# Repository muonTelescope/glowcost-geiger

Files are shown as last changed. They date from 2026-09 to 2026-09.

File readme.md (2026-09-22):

# gLowCost-geiger

A 3.3 V Geiger module for an SBM-20. An ATtiny1616 PWM-drives a boost into a 4-stage Cockcroft–Walton ladder, counts pulses, and regulates the tube voltage from PA6. Power and I²C come in on STEMMA QT. TTL is a test point. Enable is firmware.

> Prototype. The board matches this schematic's parts. New nets are not fully routed, and the high-voltage design is not bench-qualified.

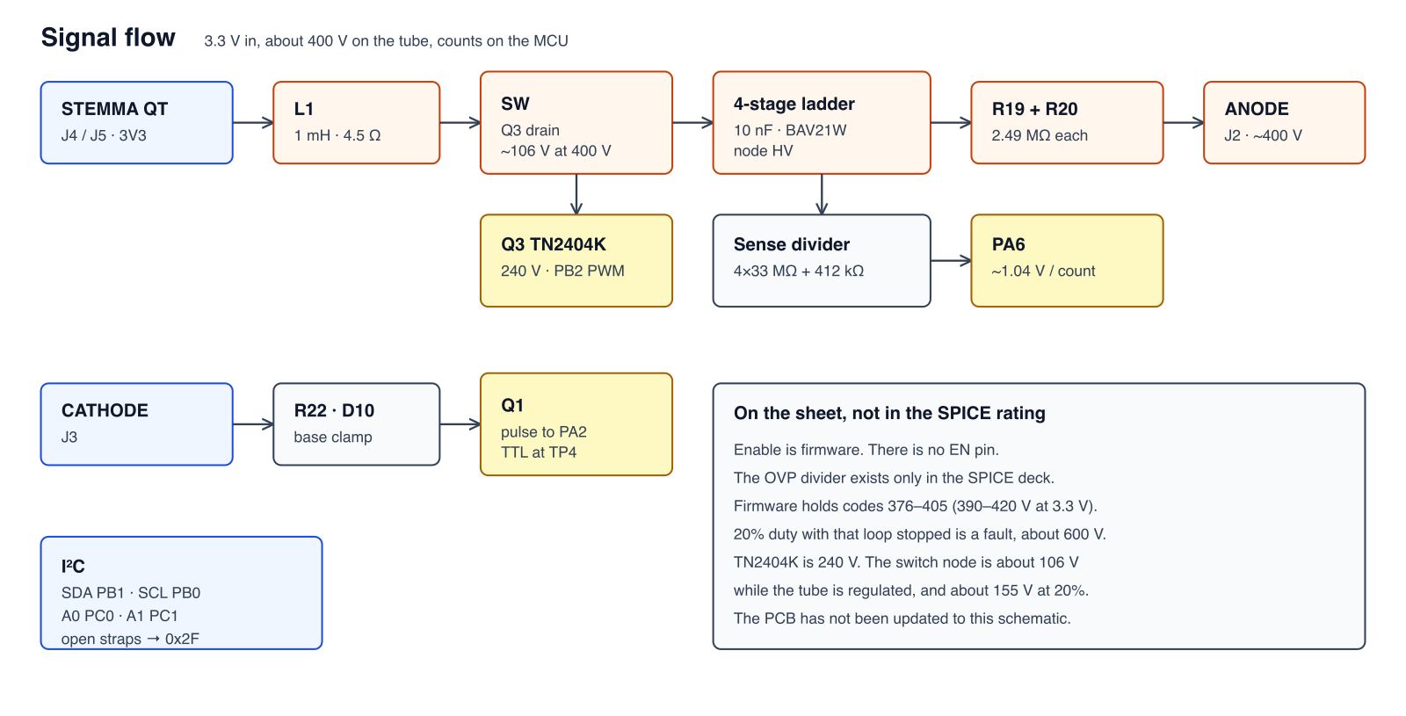
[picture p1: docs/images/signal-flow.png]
Signal flow


## Schematic

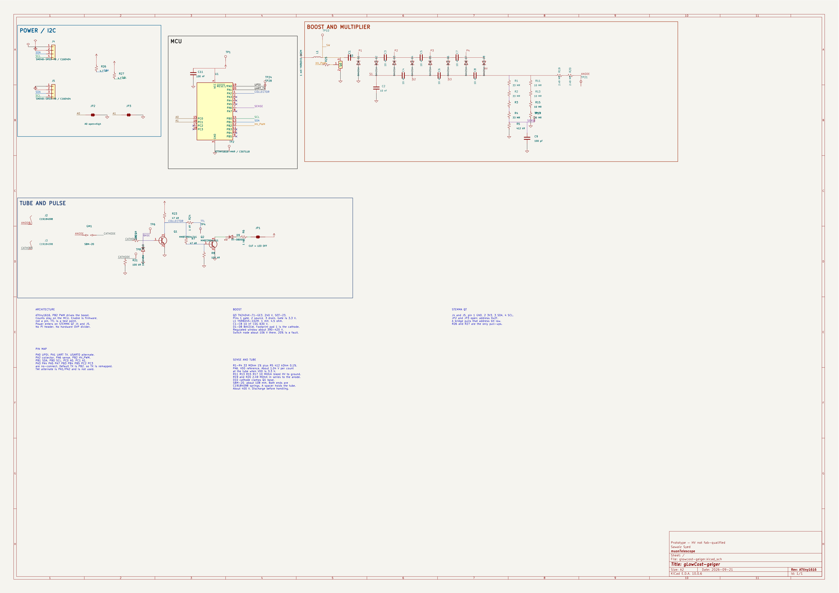
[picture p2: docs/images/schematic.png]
Schematic


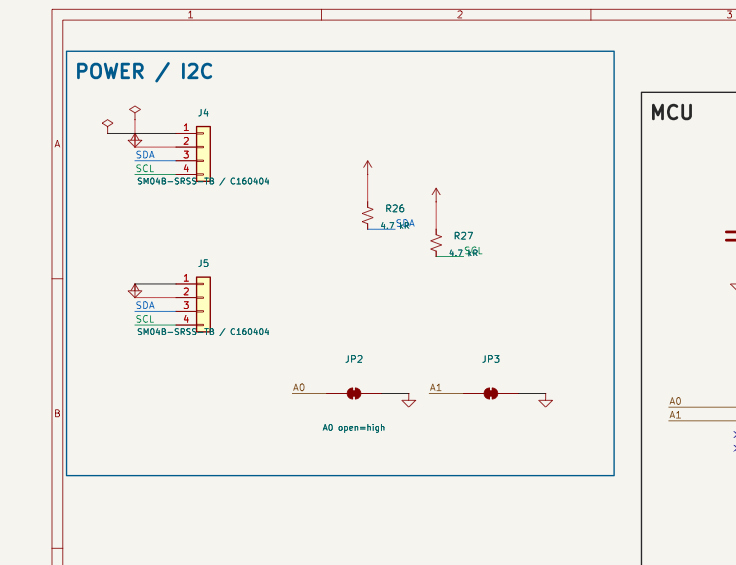
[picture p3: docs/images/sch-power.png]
Power and I2C


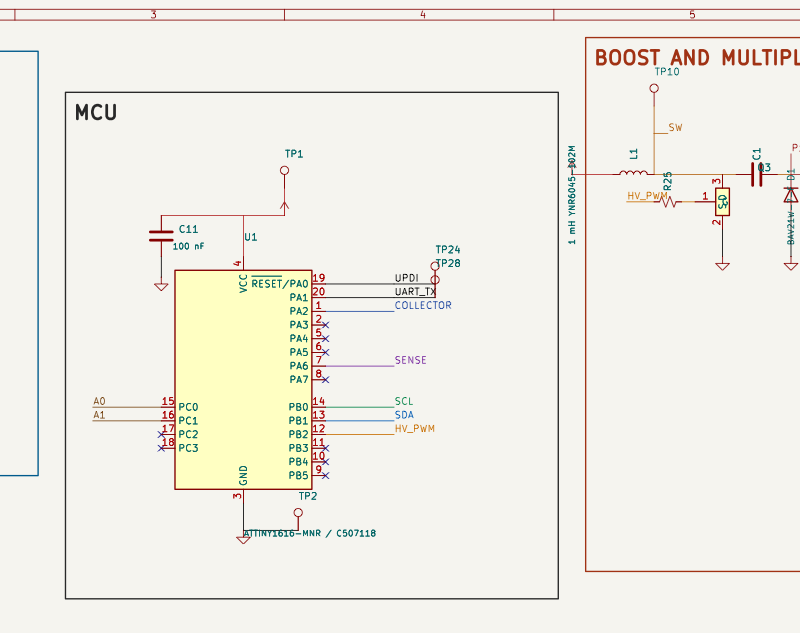
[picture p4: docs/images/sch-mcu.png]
MCU


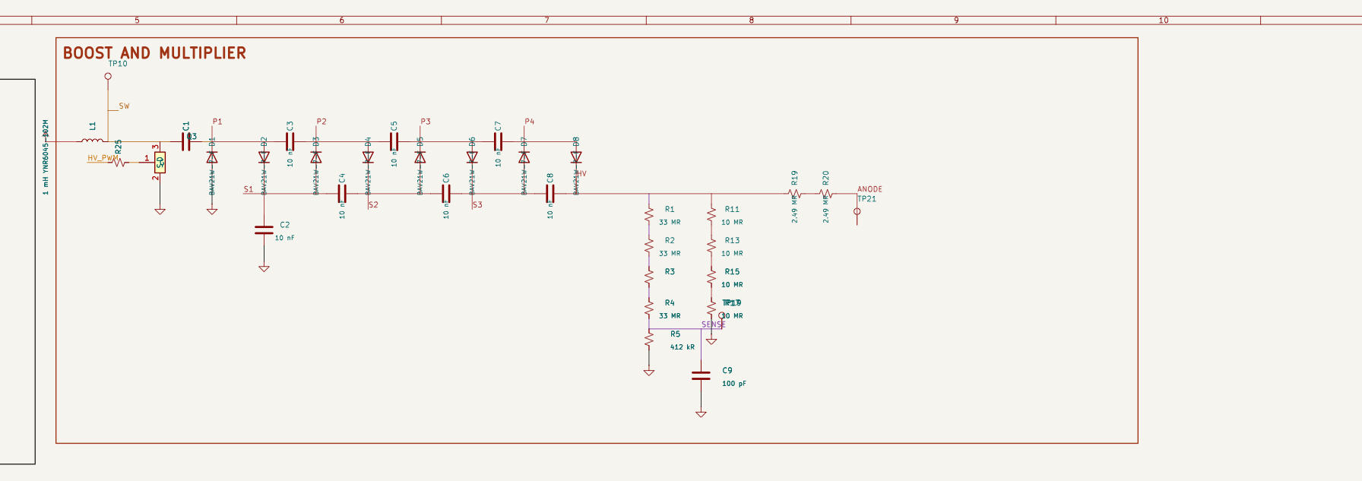
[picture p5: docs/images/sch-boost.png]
Boost and multiplier


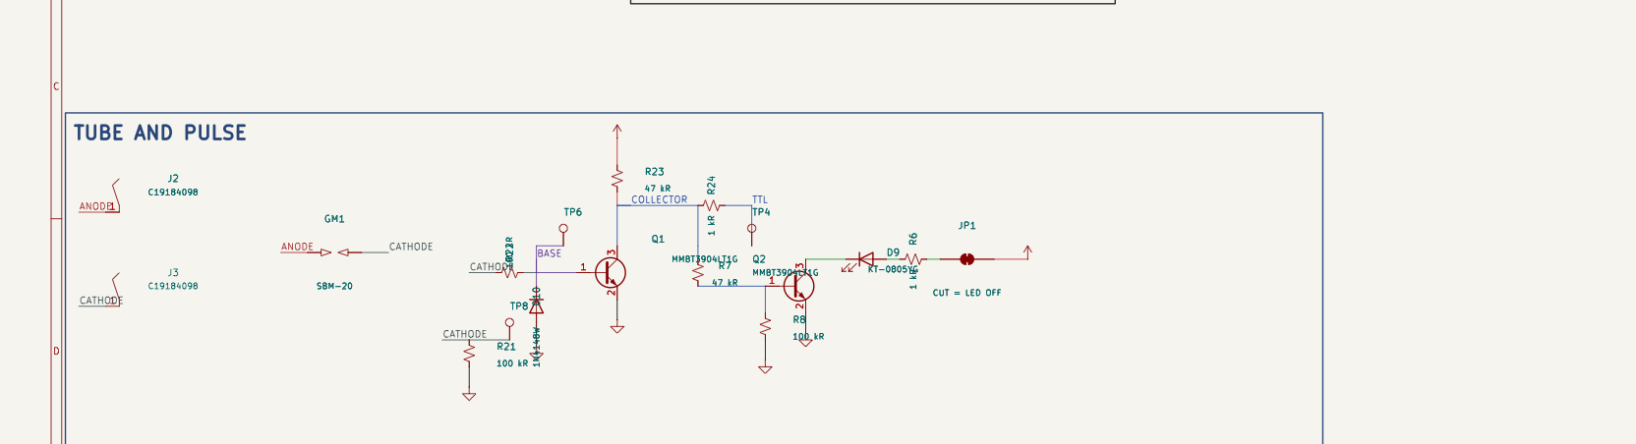
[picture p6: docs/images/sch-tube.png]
Tube and pulse


STEMMA QT pins are 1 GND, 2 3V3, 3 SDA, 4 SCL. Open address straps read `0x2F`; bridging A0, A1, or both selects `0x30`, `0x31`, or `0x32`.

| Net | Pin |
| --- | --- |
| Collector / count | PA2 |
| HV sense | PA6 |
| SDA / SCL | PB1 / PB0 |
| A0 / A1 | PC0 / PC1 |
| HV PWM | PB2 |
| UART TX | PA1 |
| UPDI | PA0 |
| TTL | TP4, from the collector through R24 |

PA3, PA4, PA5, PA7, PB3, PB4, PB5, PC2, and PC3 are no-connect. PA4 and PA5 are not I²C on this part.

Q3 is a TN2404K-T1-GE3 (240 V, SOT-23, 1 gate, 2 source, 3 drain). L1 is a YNR6045-102M, 1 mH, 4.5 Ω. The ladder is 10 nF C0G 630 V and BAV21W, pin 1 cathode. Both tube ends are JLC C19184098 (MY-AA-03). A printed spacer holds the SBM-20. J4 and J5 are SM04B-SRSS-TB (C160404) on the stock 1.00 mm JST SH footprint. C11, across VDD, is 100 nF, 50 V, X7R, 0603 (CL10B104KB8NNNC, C1591).

## High voltage

ngspice, 3.3 V, 1 µA, re-run 2026-09-21. The deck’s sense clamp is the firmware loop, not a comparator on the board. Numbers: [`docs/sim/results.csv`](docs/sim/results.csv), [`docs/sim/duty-sweep.csv`](docs/sim/duty-sweep.csv).

| At 3.3 V, 1 µA | |
| --- | --- |
| Tube voltage, 150–190 ms | 399 V (396–404 V) |
| Time to ~396 V | 30 ms |
| Switch peak | 106 V |
| Inductor peak | 62 mA |
| Input current | 2.35 mA |

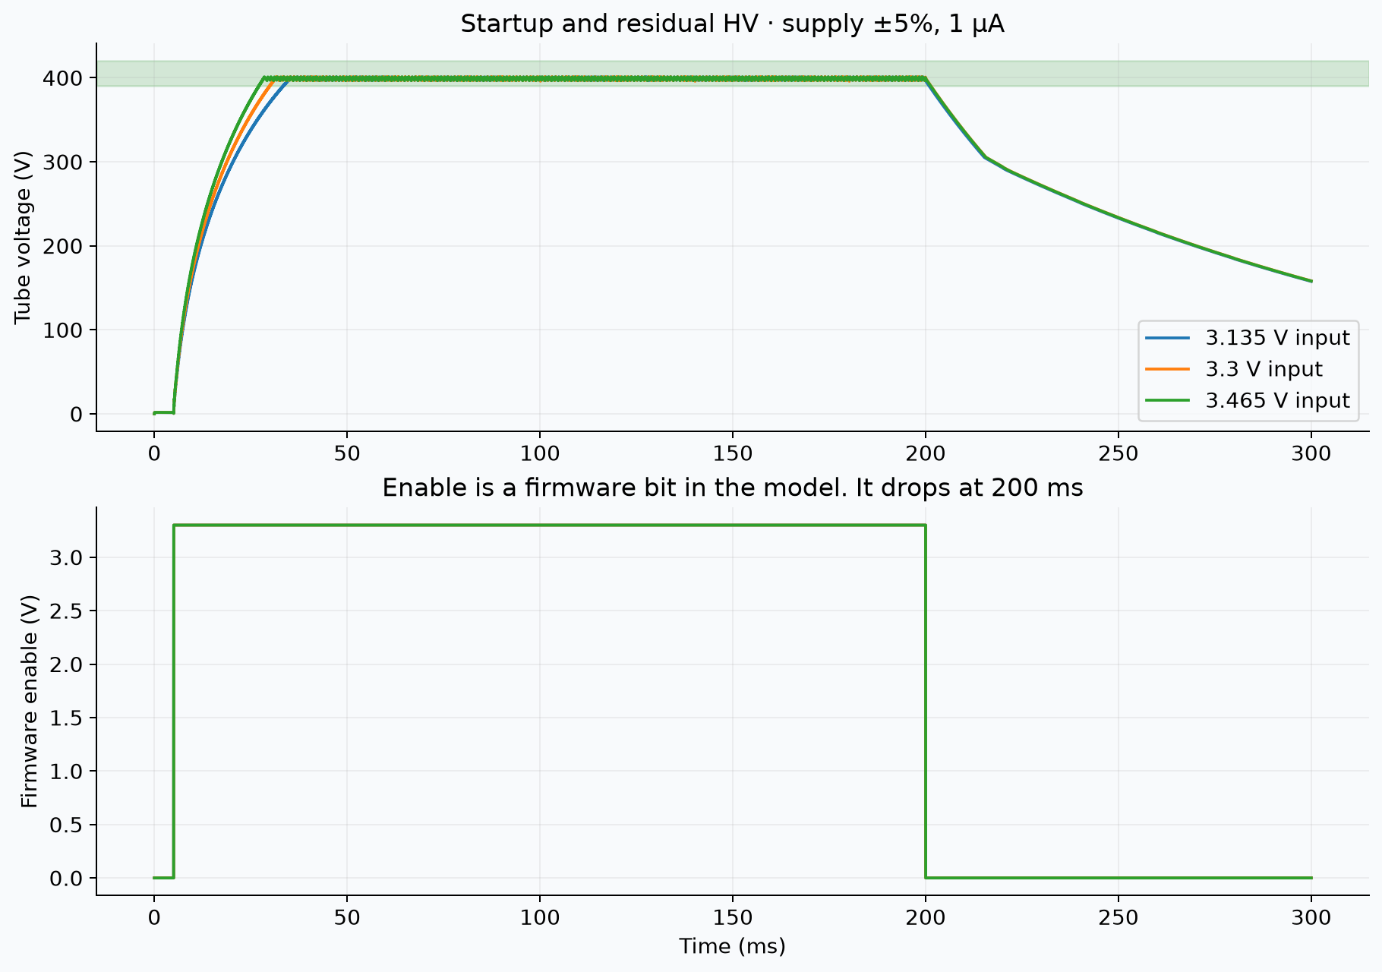
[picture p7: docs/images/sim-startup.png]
Startup


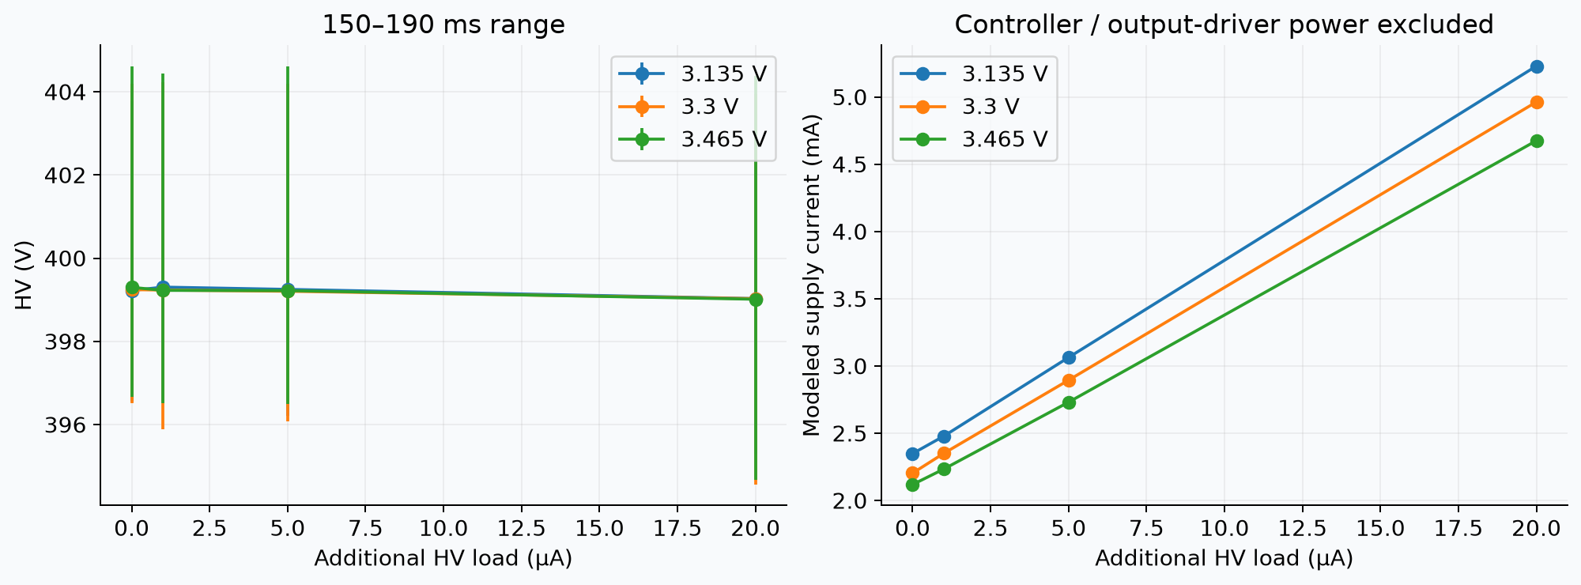
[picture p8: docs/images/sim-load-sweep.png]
Load


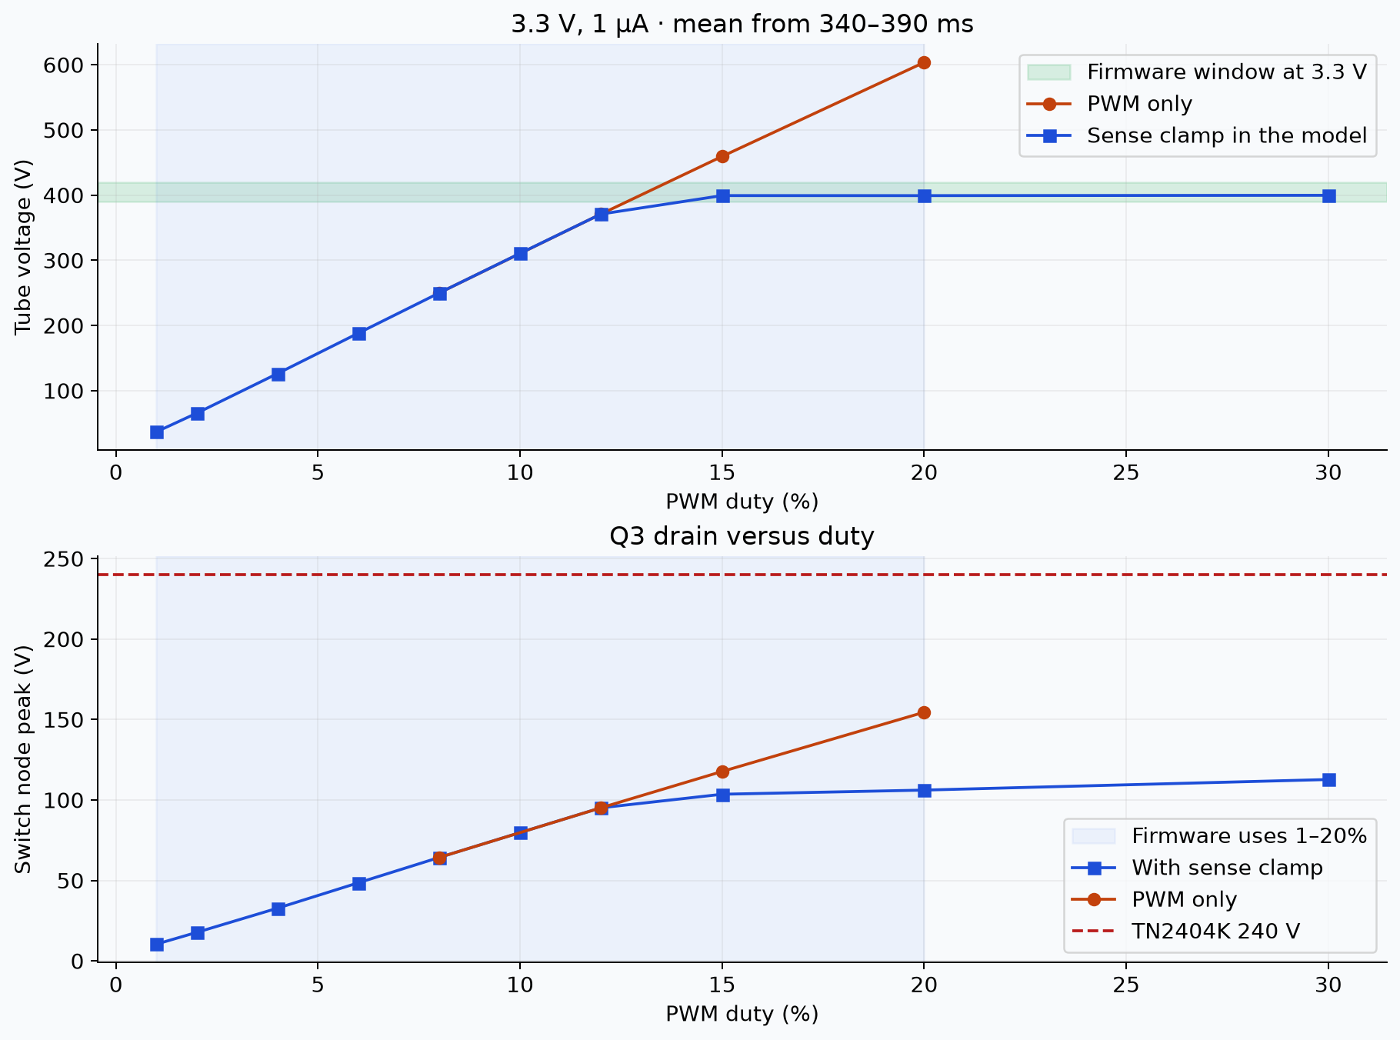
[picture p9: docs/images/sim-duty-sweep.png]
Duty


From 2% to 12% the plant rises about 30.5 V per percent of duty, about 1.5 V per timer count. The model holds 399 V once the sense node reaches 1.242 V. With that clamp removed, 20% duty runs to 604 V and the switch node to 155 V. TN2404K is 240 V, so that fault is inside the drain rating. Firmware stays at 0% until the host enables it, then starts at 1% and steps one count every 10 ms until PA6 is near 386. Duty cannot pass 20% (CMP2 400). Codes 405 and 376 remain the trip and the recover point.

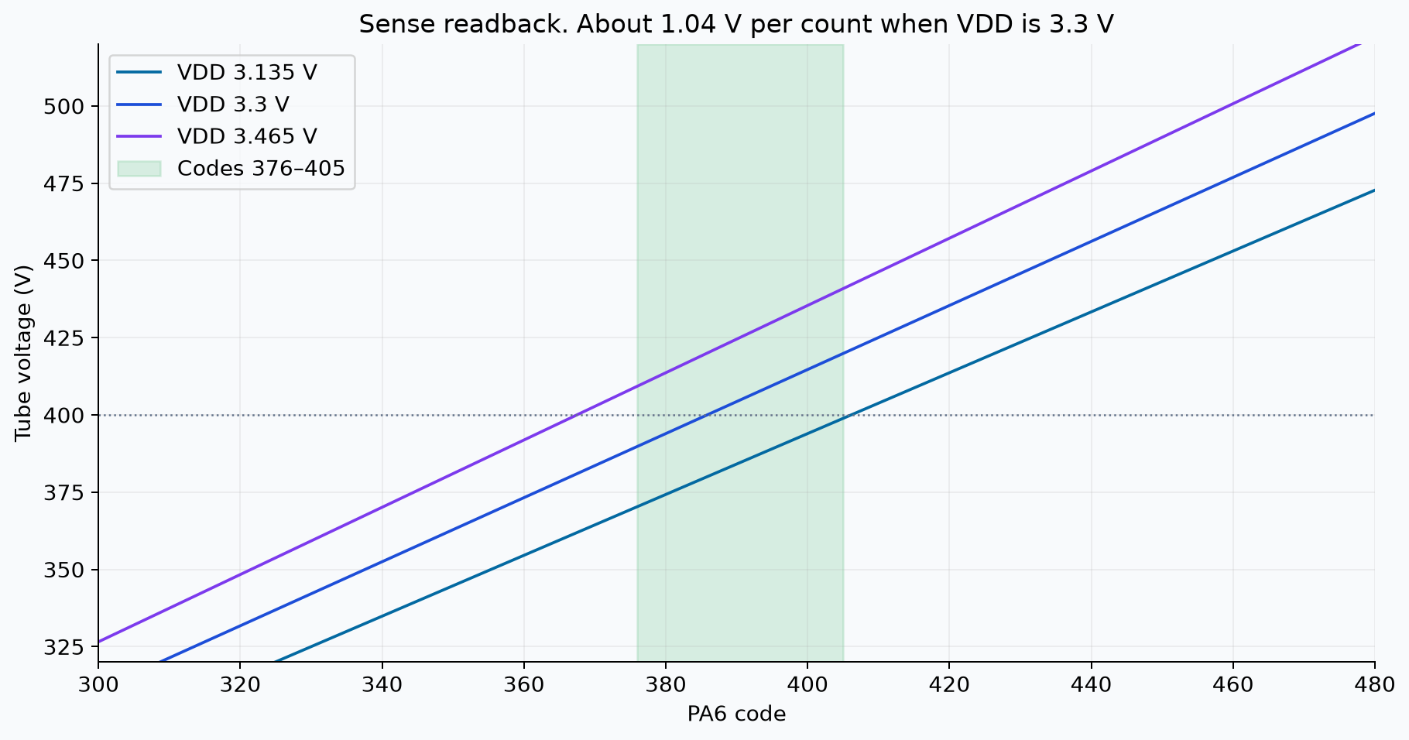
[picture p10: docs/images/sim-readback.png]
Readback


| | Code | 3.135 V | 3.3 V | 3.465 V |
| --- | --- | --- | --- | --- |
| Recover | 376 | 370 V | 390 V | 409 V |
| 400 V | 386 | 380 V | 400 V | 420 V |
| Trip | 405 | 399 V | 420 V | 441 V |

The ADC reference is VDD, so those codes move about ±5% with the rail.

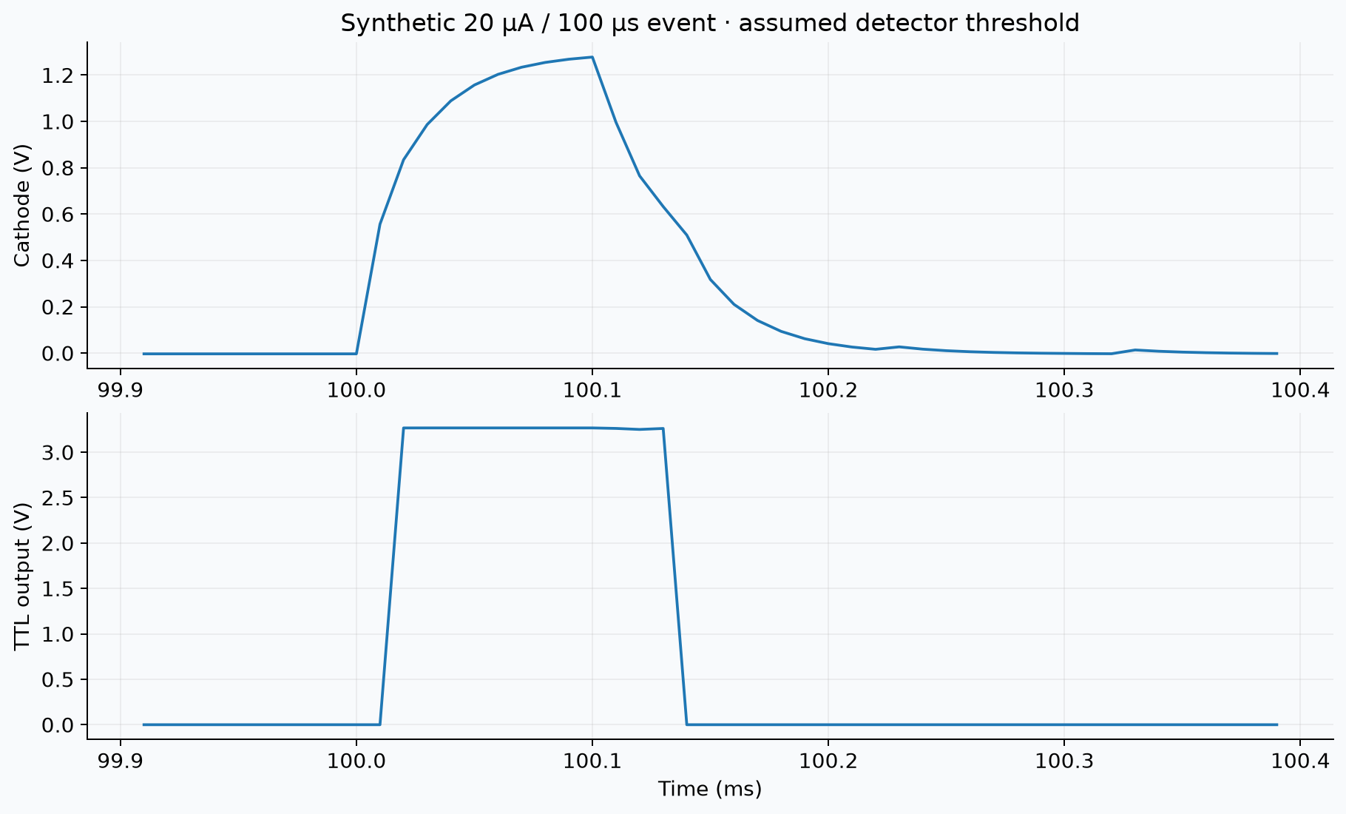
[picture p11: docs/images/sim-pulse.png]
Pulse


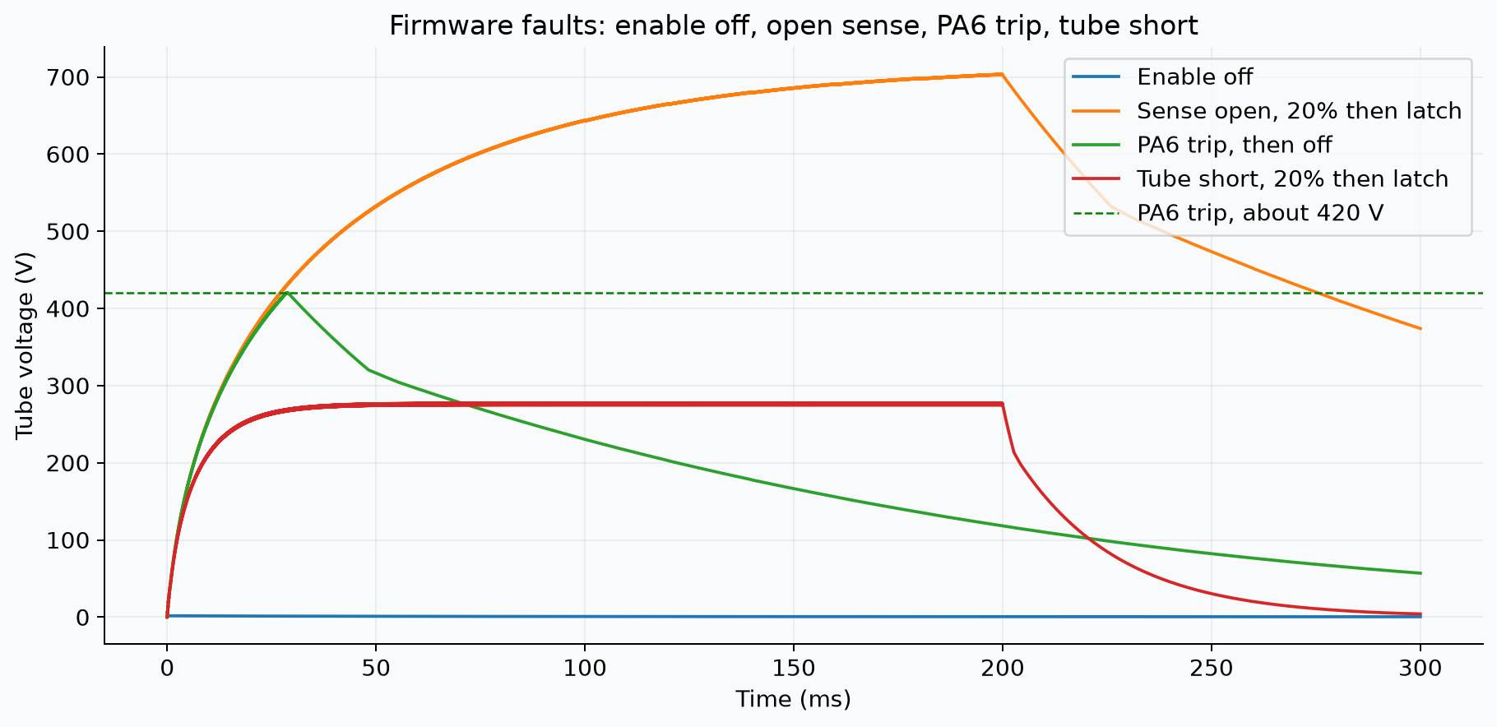
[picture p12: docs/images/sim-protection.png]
Faults


The fault traces follow the firmware. With the sense path open, nothing trips, so the converter sits at the 20% ceiling until the latch. With PA6 working, the duty clears when that divider crosses the trip. The ceiling traces start already at 20%; the climb from 1% takes about 3.8 s. After a real trip the firmware starts again at 1% once PA6 falls to code 376. This trip trace leaves the duty off.

| Case | Peak tube voltage |
| --- | --- |
| Enable held off | 1.7 V |
| Sense open, 20% for 200 ms, then latch | 705 V, switch 179 V |
| PA6 reaches the trip | 423 V, then the duty stays off |
| 1 kΩ across the tube, 20% for 200 ms, then latch | 281 V |

```bash
python3 scripts/simulate.py
python3 scripts/duty_sweep.py
```

## Firmware

`firmware/main.c` is the I²C slave and the HV loop. Boot leaves the boost off. A write to CTRL bit 0 starts at 1% and steps duty until PA6 is near code 386 (~400 V at 3.3 V). Trip is 405, recover is 376, and a 20% ceiling that still reads low latches off. Counts are a running total plus the previous second, on the strapped address (`0x2F` open). The register map is in [`firmware/README.md`](firmware/README.md). Build with `make -C firmware` (`avr-gcc`, UPDI).

## Board

The outline is 120 × 48 mm. J2 and J3 are both JLC C19184098, at the ends of the SBM-20. The ATtiny, inductor, switch, and STEMMA QT connectors sit on the bay along the lower edge. Multiplier copper was kept where it still matched the sheet. DRC reports 56 open connections, so the new nets are not fully routed. The 0.4 mm VQFN is tighter than the 0.25 mm clearance rule. Creepage is not fab-qualified. Discharge the multiplier before handling. The printed spacer is not in the board file.

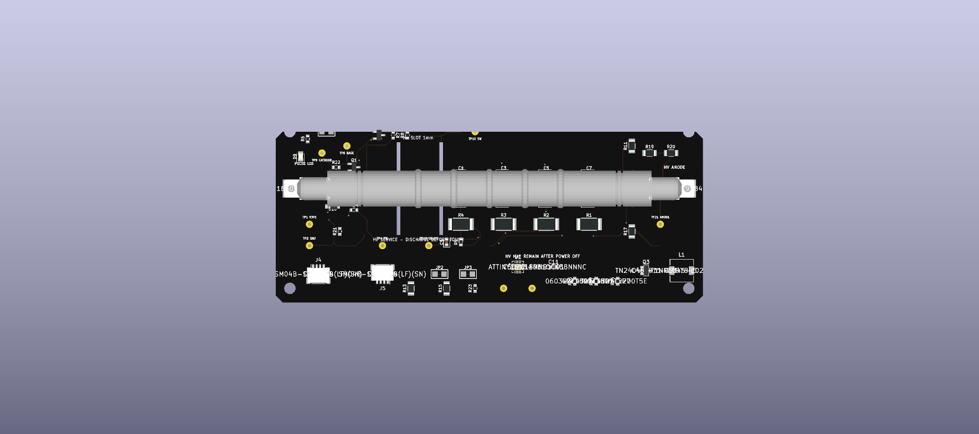
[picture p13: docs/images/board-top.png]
Top


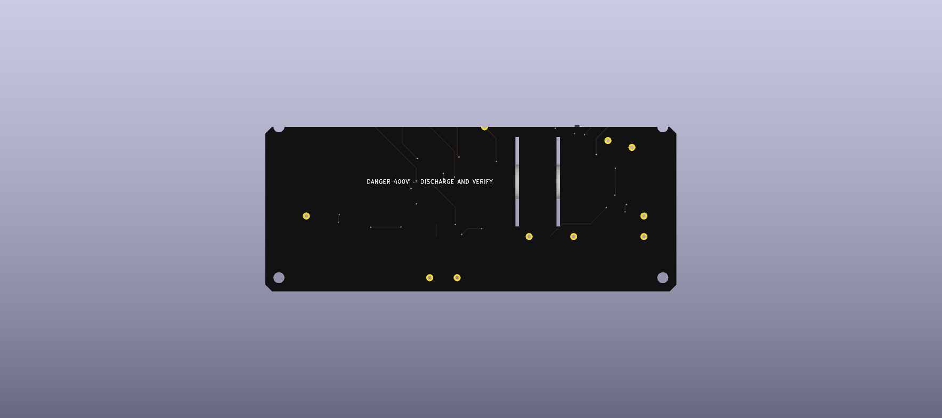
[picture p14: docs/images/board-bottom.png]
Bottom


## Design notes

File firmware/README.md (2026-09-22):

# firmware

ATtiny1616 firmware for gLowCost-geiger. CTC-5 / STS-5 and SBM-20 use the same ~400 V setpoint. The tube byte only records which one is fitted.

## Build

```bash
make -C firmware
```

Requires an `avr-gcc` that includes the ATtiny1616 header (Homebrew `osx-cross/avr/avr-gcc@14` does; the `@9` avr-libc does not). The Makefile uses `@14` when it is installed and the `avr-gcc` on `PATH` is too old. Flash with `make -C firmware flash` (pymcuprog / UPDI). The image clears the factory clock prescaler and runs at 20 MHz from the internal oscillator.

## High voltage

PB2 (TCA0 WO2) is 10 kHz. Boot leaves the duty at 0, so the tube stays down until the host sets CTRL bit 0. Enabling starts at 1% and steps one timer count every 10 ms until PA6 is near code 386 (~400 V when VDD is 3.3 V). The hold band is ±8 counts. Duty stops at 400 counts (20%).

- Code 405 (~420 V) clears the duty. It restarts at 1% once the sense falls to 376 (~390 V).
- If duty sits at the 20% ceiling for 200 ms and the sense is still below the setpoint, the loop latches off. An open sense wire or a tube short does this. Write control 0, then 1, to try again.
- Register `TARGET` can move the setpoint. Values are clamped to 200…404 so a host write stays under the trip.
- The 412 kΩ sense leg is sampled slowly (ADC clock /64, longest sample) because that node is high impedance.

There is no enable pin. PB3 is unconnected.

## Pulses

PA2 counts the rising edge on Q1’s collector. A blank of about 200–300 µs drops a second edge from the same pulse. That blank is not a measured tube dead time, and the firmware does not convert counts to dose rate.

## I2C

TWI0 slave on PB1 SDA and PB0 SCL. Pull-ups are R26 and R27. Open straps read `0x2F`. Bridging A0 (PC0), A1 (PC1), or both to ground selects `0x30`, `0x31`, or `0x32`.

Write the register address, then data. A repeated start reads from that address. Multi-byte values are little-endian. Each read transaction copies the live values once, at SLA+R.

| Addr | Name | Access | Contents |
| --- | --- | --- | --- |
| `0x00` | ID | R | `0x47` |
| `0x01` | FW | R | `0x01` |
| `0x02` | STATUS | R | bit0 HV on, bit1 OVP, bit2 in band, bit3 latched fail |
| `0x03` | CTRL | R/W | bit0 `1` run, `0` stop and clear a latch |
| `0x04` | COUNT | R | uint32 pulses since boot or the last clear |
| `0x08` | CPS | R | uint16 pulses in the previous RTC second |
| `0x0A` | HV_ADC | R | uint16 latest PA6 code |
| `0x0C` | DUTY | R | uint16 PWM compare |
| `0x0E` | TARGET | R/W | uint16 PA6 setpoint, default 386 |
| `0x10` | TUBE | R/W | `0` either, `1` CTC-5/STS-5, `2` SBM-20 |
| `0x11` | CMD | W | `0xA5` clears COUNT |

USART0 alternate TX on PA1 still prints the address and a one-second line at 115200 8N1. There is no interrupt pin back to the host.

```python
# Bus 1, open straps. smbus2 or the kernel i2c interface.
bus.write_byte_data(0x2F, 0x03, 0x01)  # HV on
block = bus.read_i2c_block_data(0x2F, 0x04, 6)  # COUNT, CPS
```

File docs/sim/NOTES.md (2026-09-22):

# HV model

`sim/hv/converter.cir` is an exploratory ngspice deck. The switch is an ideal 2 Ω device, the diodes break at 250 V, and controller current is not included. L1 is 1 mH at 4.5 Ω.

D1–D8 on the sheet are BAV21W-7-F (LCSC C155214), catalog 200 V DC reverse. The deck’s 250 V breakdown is a generic diode, not that part. A stuck 20% duty puts about 155 V on the switch node. Per-diode reverse voltage and hot leakage were not remeasured. The ladder stays 10 nF C0G. The X7R voltage-bias warning belongs to that high-voltage chain, not to C11 at 3.3 V.

A 2026-09-15 study quoted 250 µs as a planning dead time, taken from a counter manual’s 190 µs STS-5/SBM-20 figure, and about 5.1 mA for a controller this sheet no longer has. Neither number was remeasured here. This deck’s 2.35 mA excludes the MCU. Dose rate was not calculated.

What the deck adds, and the board does not:

- `EN` is the firmware enable bit, modeled as a voltage source.
- The regulated traces still use a fast clamp at the setpoint, including the 402 kΩ `ovp` chain. That chain is not on the sheet. The sheet regulates from PA6.
- The fault traces delete that clamp. Enable off stays at 1.7 V. An open sense path has no trip, so 20% duty runs to about 705 V with a 179 V switch peak, then the 200 ms ceiling latch drops the duty. A working PA6 divider cuts the duty at about 423 V. A 1 kΩ tube short peaks at about 281 V and then latches the same way. Those ceiling traces start at 20%; the firmware takes about 3.8 s to climb there from 1%, and a real trip restarts at 1% after code 376.
- With the sense divider still connected, the open-loop duty sweep at 20% is about 604 V and the switch peak is about 155 V. Q3 on the sheet is a 240 V TN2404K. The diodes in this deck break at 250 V.

Re-run:

```bash
python3 scripts/simulate.py
python3 scripts/duty_sweep.py
```

Latest tables are [`results.csv`](results.csv) and [`duty-sweep.csv`](duty-sweep.csv). Plots are in [`../images`](../images). The 2026-09-21 suite passed on ngspice 47: 399 V regulated at 3.3 V and 1 µA, switch peak 106 V.

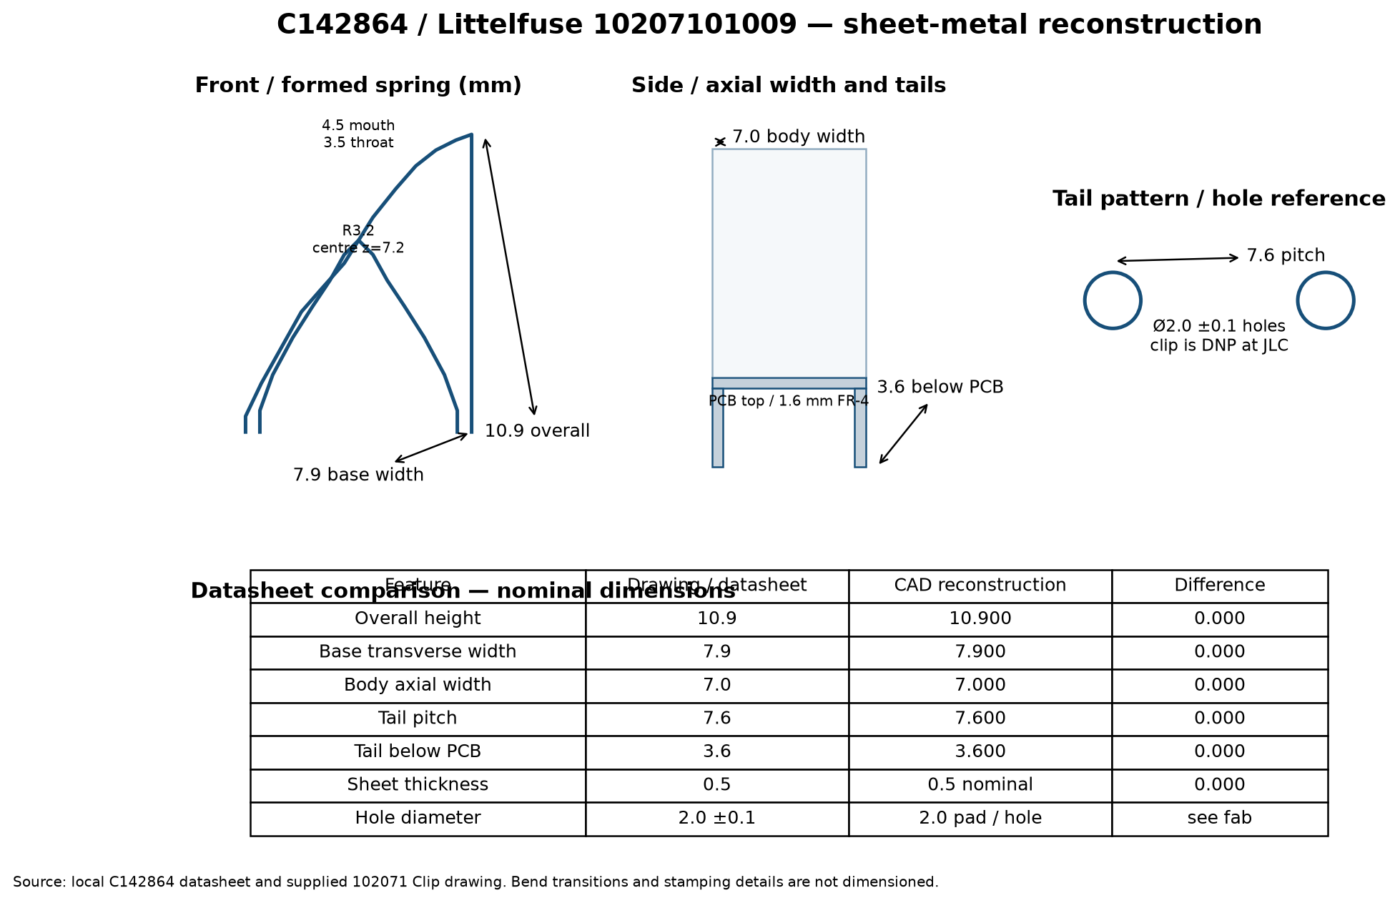
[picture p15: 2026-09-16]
docs/images/clip-comparison.png

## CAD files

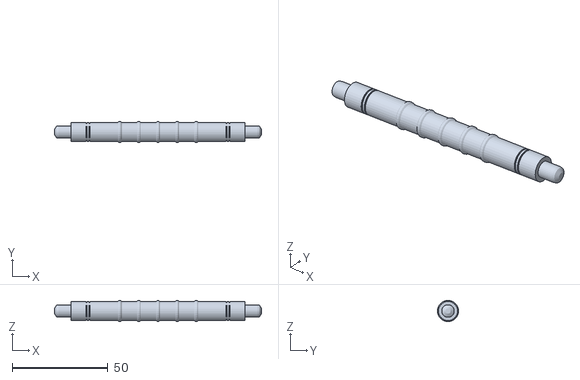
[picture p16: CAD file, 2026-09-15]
cad/models/tube.stl
108.0 x 11.0 x 11.0

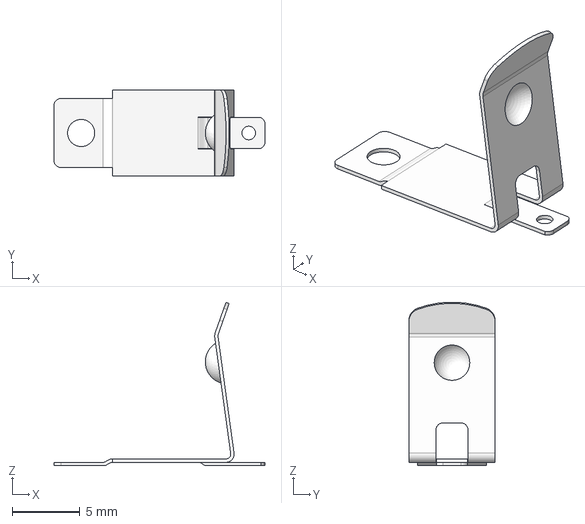
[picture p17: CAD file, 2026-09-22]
pcb/components/MY-AA-03/MY-AA-03.step
15.5 x 6.35 x 12.0 mm

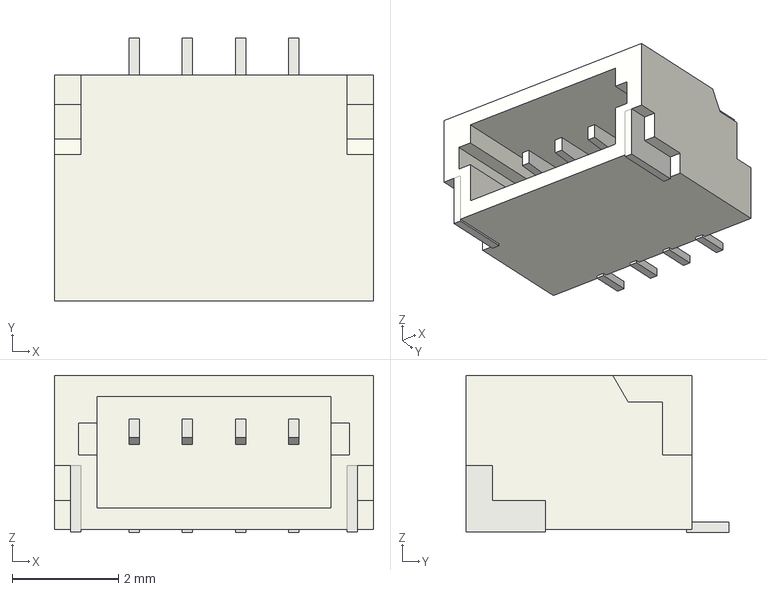
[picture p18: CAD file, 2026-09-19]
pcb/models/JST_SH_SM04B-SRSS-TB_1x04-1MP_P1.00mm_Horizontal.step
6.00 x 4.95 x 2.96 mm

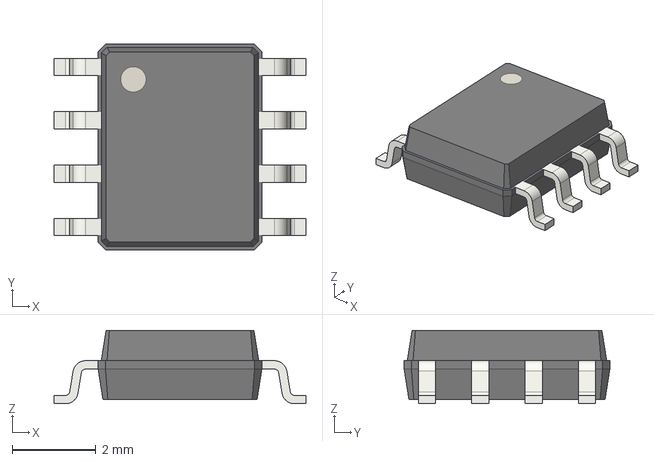
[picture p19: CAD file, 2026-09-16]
pcb/models/SOIC-8_3.9x4.9mm_P1.27mm.step
6.00 x 4.90 x 1.75 mm

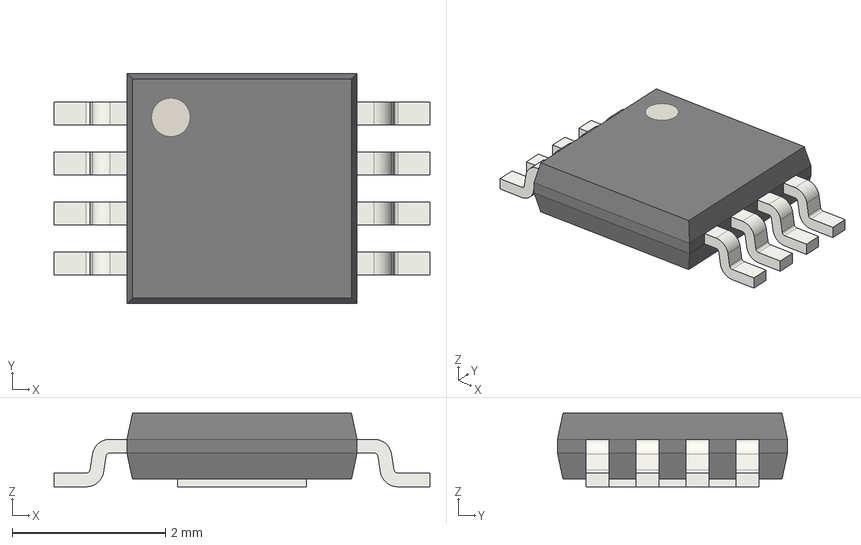
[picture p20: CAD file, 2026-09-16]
pcb/models/MSOP-8-1EP_3x3mm_P0.65mm_EP1.68x1.88mm.step
4.90 x 3.00 x 0.96 mm

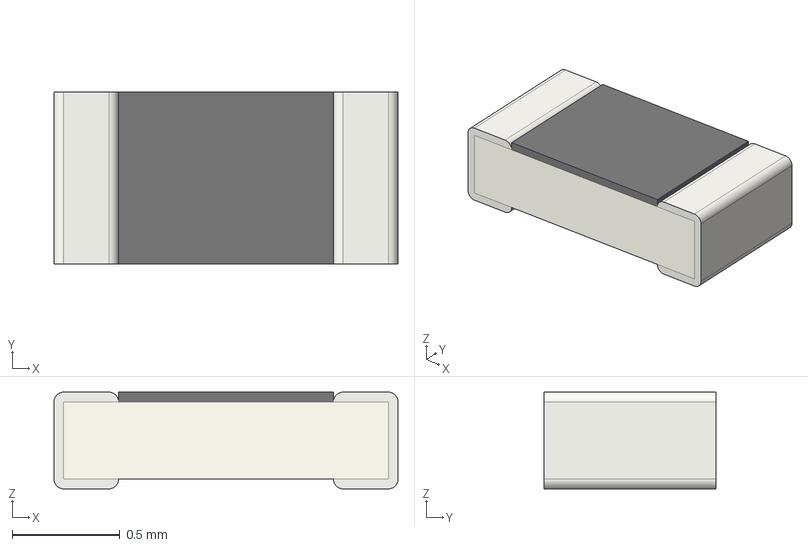
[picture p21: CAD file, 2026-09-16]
pcb/models/R_0603_1608Metric.step
1.60 x 0.8 x 0.45 mm

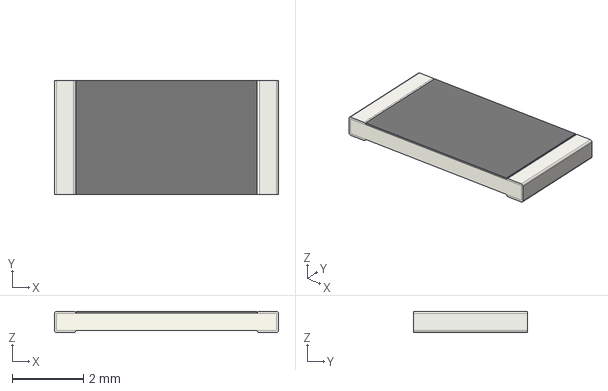
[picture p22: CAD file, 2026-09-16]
pcb/models/R_2512_6332Metric.step
6.30 x 3.20 x 0.6 mm

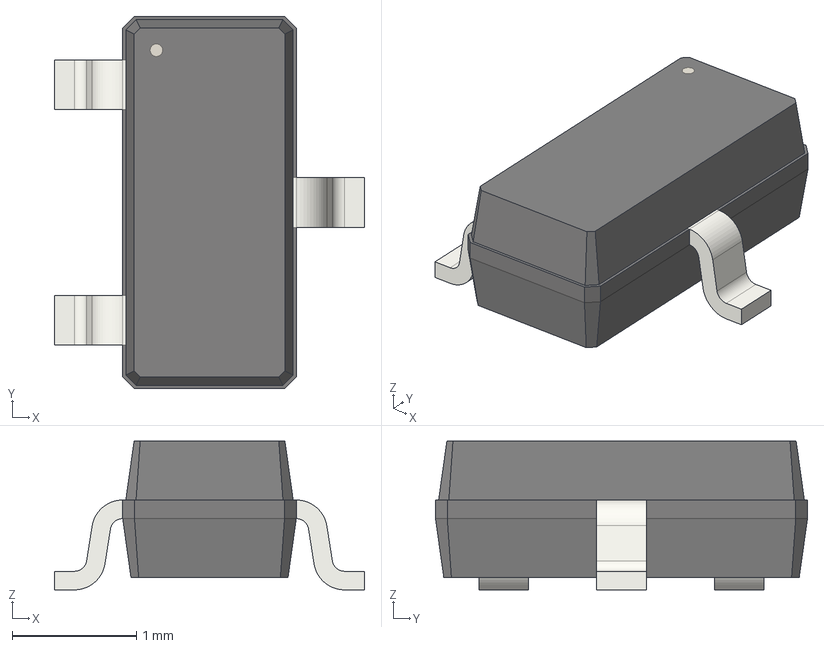
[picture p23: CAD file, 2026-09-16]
pcb/models/SOT-23.step
2.50 x 3.00 x 1.20 mm

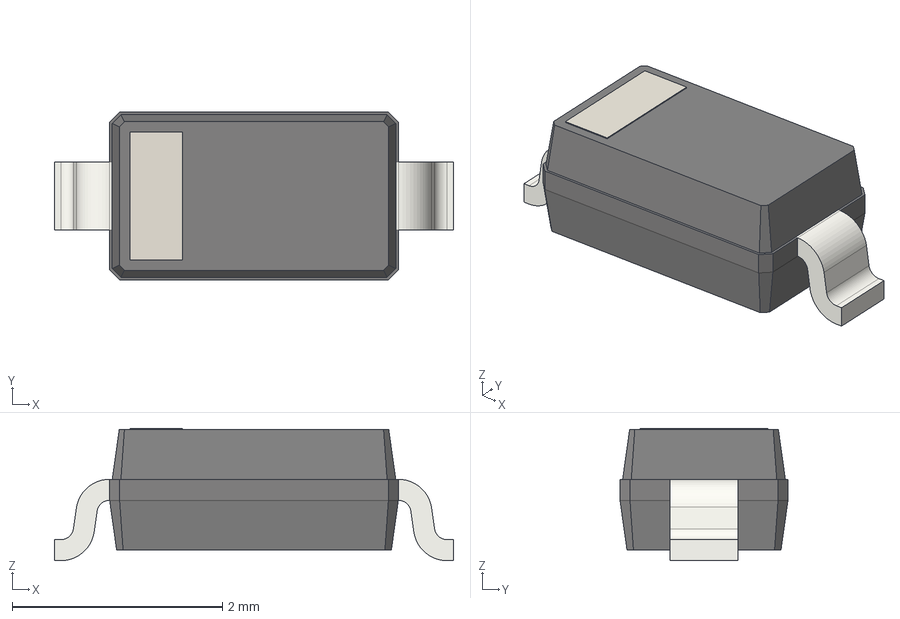
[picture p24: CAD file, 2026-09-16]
pcb/models/D_SOD-123.step
3.80 x 1.60 x 1.26 mm

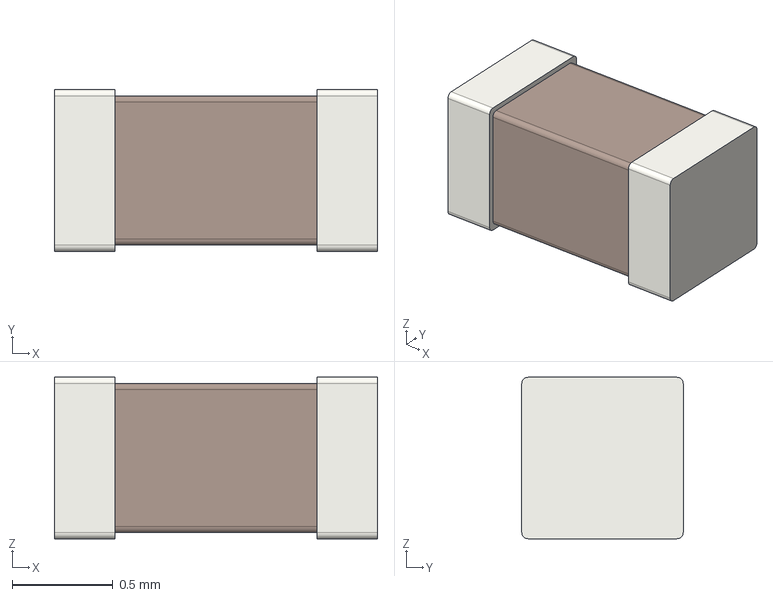
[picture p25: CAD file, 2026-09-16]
pcb/models/C_0603_1608Metric.step
1.60 x 0.8 x 0.8 mm

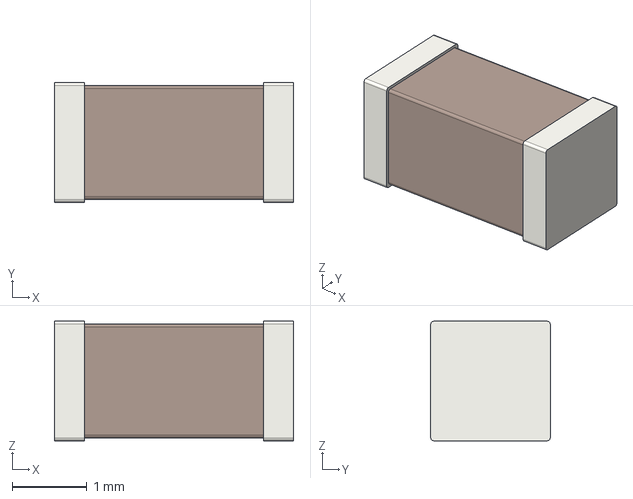
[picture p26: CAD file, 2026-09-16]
pcb/models/C_1206_3216Metric.step
3.20 x 1.60 x 1.60 mm

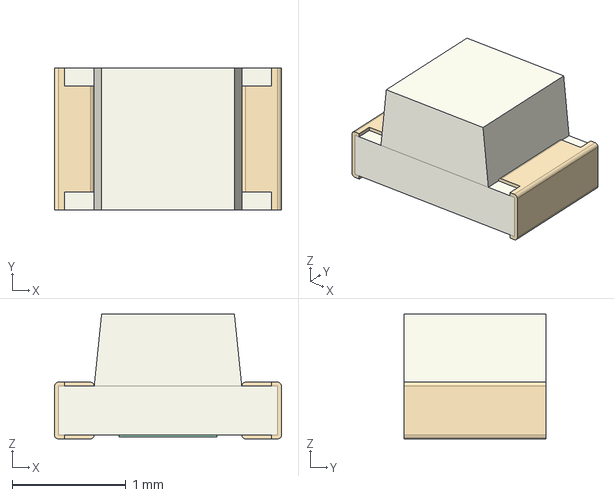
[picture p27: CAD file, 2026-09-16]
pcb/models/LED_0805_2012Metric.step
2.00 x 1.25 x 1.10 mm

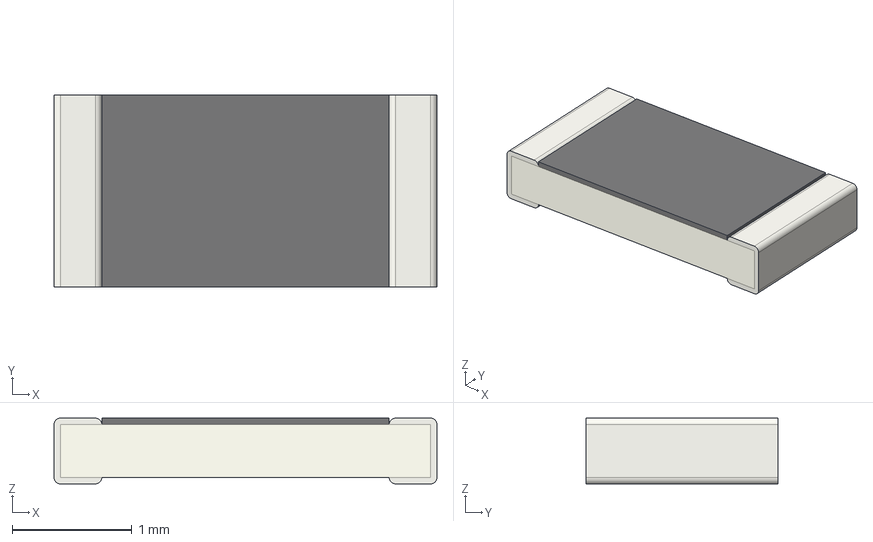
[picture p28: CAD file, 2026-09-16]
pcb/models/R_1206_3216Metric.step
3.20 x 1.60 x 0.55 mm

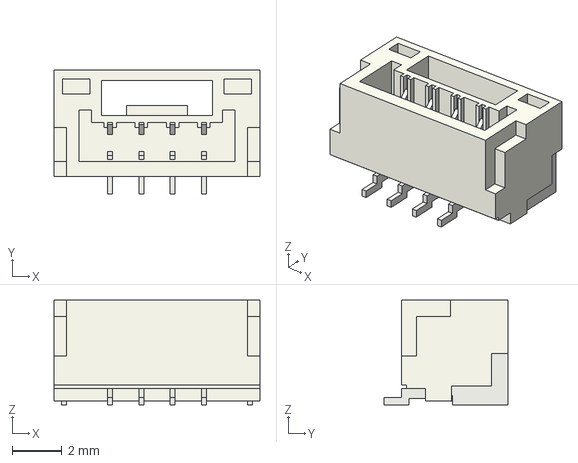
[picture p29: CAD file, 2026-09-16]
pcb/models/JST_GH_BM04B-GHS-TBT_1x04-1MP_P1.25mm_Vertical.step
8.25 x 4.95 x 4.20 mm

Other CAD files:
pcb/models/tube.step
cad/models/C142864/C142864.FCStd
pcb/models/C142864.step
cad/models/C142864/C142864.stl
cad/models/SBM-20-reference.ipt
cad/models/tube.blend

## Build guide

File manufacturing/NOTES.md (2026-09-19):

# Manufacturing

Production Gerbers, BOM, and CPL belong in GitHub Releases, not this tree.

When ready to fab, export from `pcb/glowcost-geiger.kicad_pcb` and park order notes here.

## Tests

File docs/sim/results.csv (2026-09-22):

case | vbat | load_uA | hv_mean | hv_min | hv_max | ripple_pp | startup_ms | peak_hv_V | peak_switch_v | peak_inductor_mA | input_mA | ovp_peak_V | ttl_min_V | ttl_max_V | base_peak_V | hv_at_300ms_V | within_360_440
v3.135_load0 | 3.135 | 0.0 | 399.2208044236833 | 396.552789 | 403.765313 | 7.2125239999999735 | 33.320415399999995 | 403.820829 | 105.633667 | 58.886013500000004 | 2.3482368066069212 | 1.21826569 | -0.0152090036 | 3.13215383 | 0.599440284 | 170.254813 | True
v3.135_load1 | 3.135 | 1.0 | 399.3030274777249 | 396.558332 | 403.804286 | 7.245953999999983 | 33.920569300000004 | 403.810477 | 105.587097 | 58.8860552 | 2.477993273104114 | 1.21823861 | -1.76063756e-06 | 3.13112917 | 0.599438588 | 157.598234 | True
v3.135_load5 | 3.135 | 5.0 | 399.2482664800428 | 396.214124 | 403.78454 | 7.570415999999966 | 37.020540999999994 | 403.787062 | 105.544523 | 58.885991 | 3.06297475890981 | 1.21813945 | -0.0152090036 | 3.13130217 | 0.599437593 | 108.639413 | True
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

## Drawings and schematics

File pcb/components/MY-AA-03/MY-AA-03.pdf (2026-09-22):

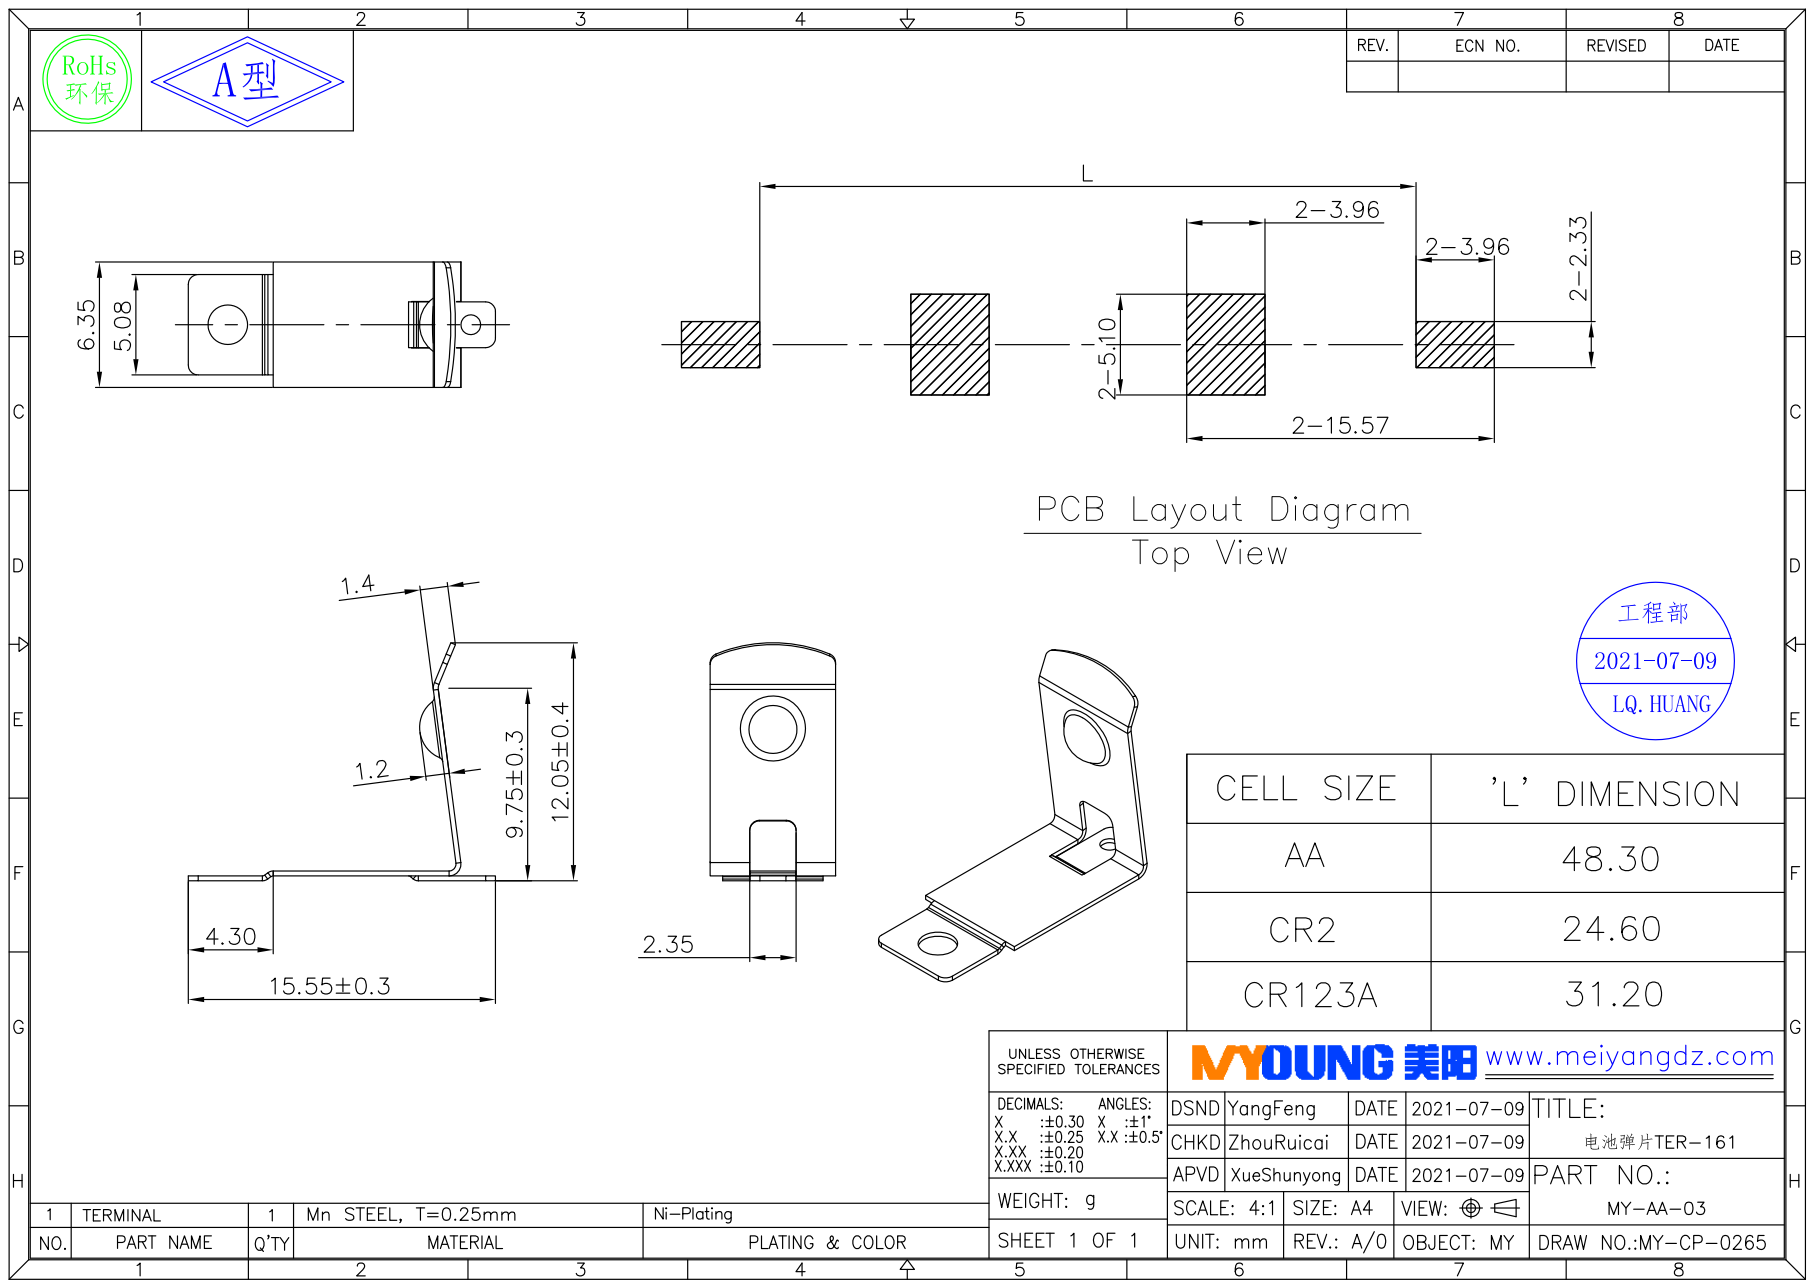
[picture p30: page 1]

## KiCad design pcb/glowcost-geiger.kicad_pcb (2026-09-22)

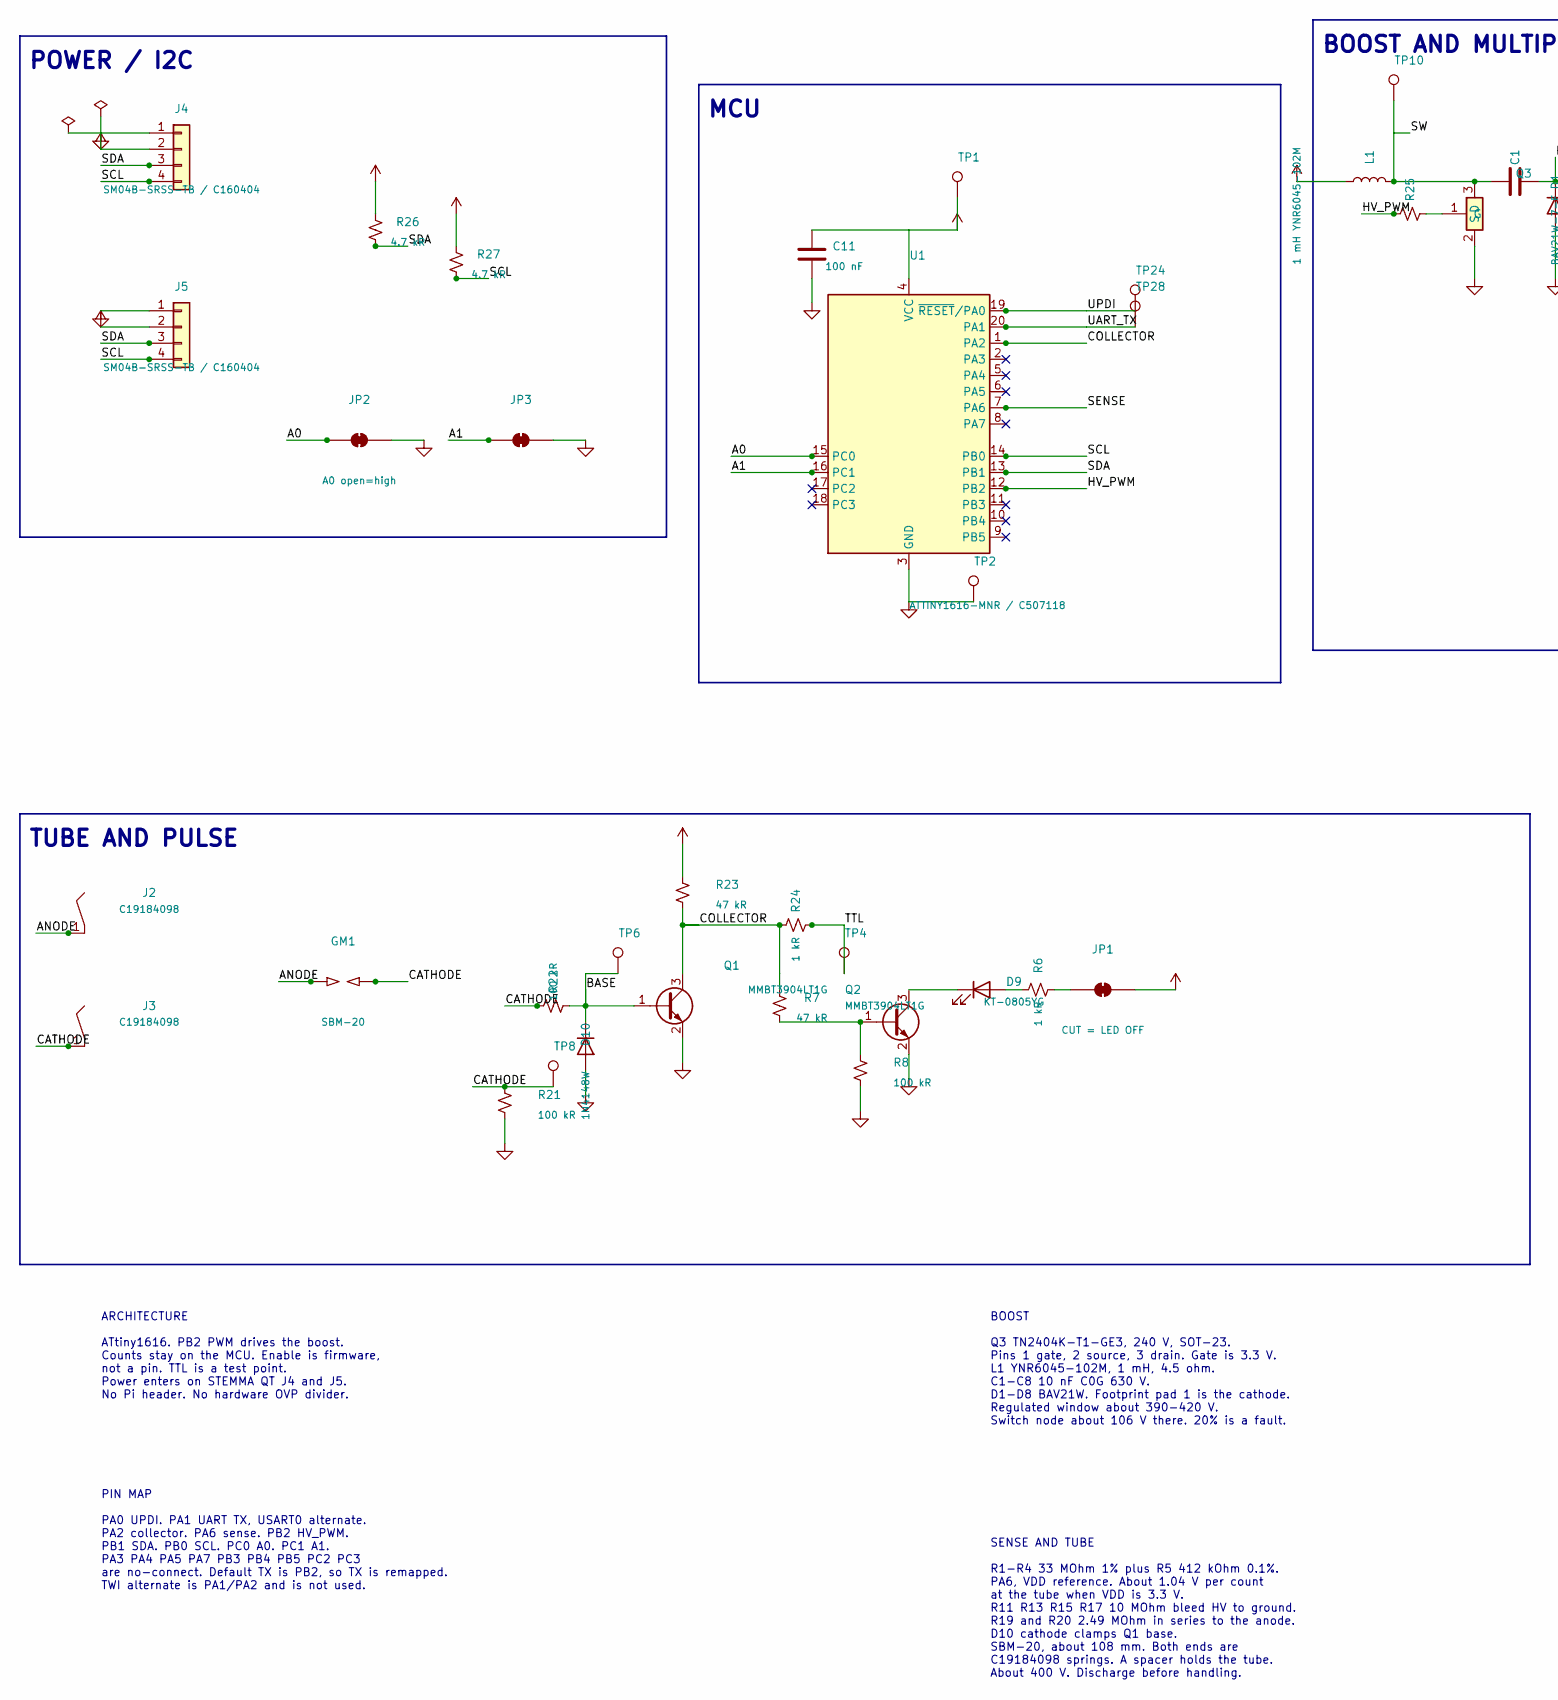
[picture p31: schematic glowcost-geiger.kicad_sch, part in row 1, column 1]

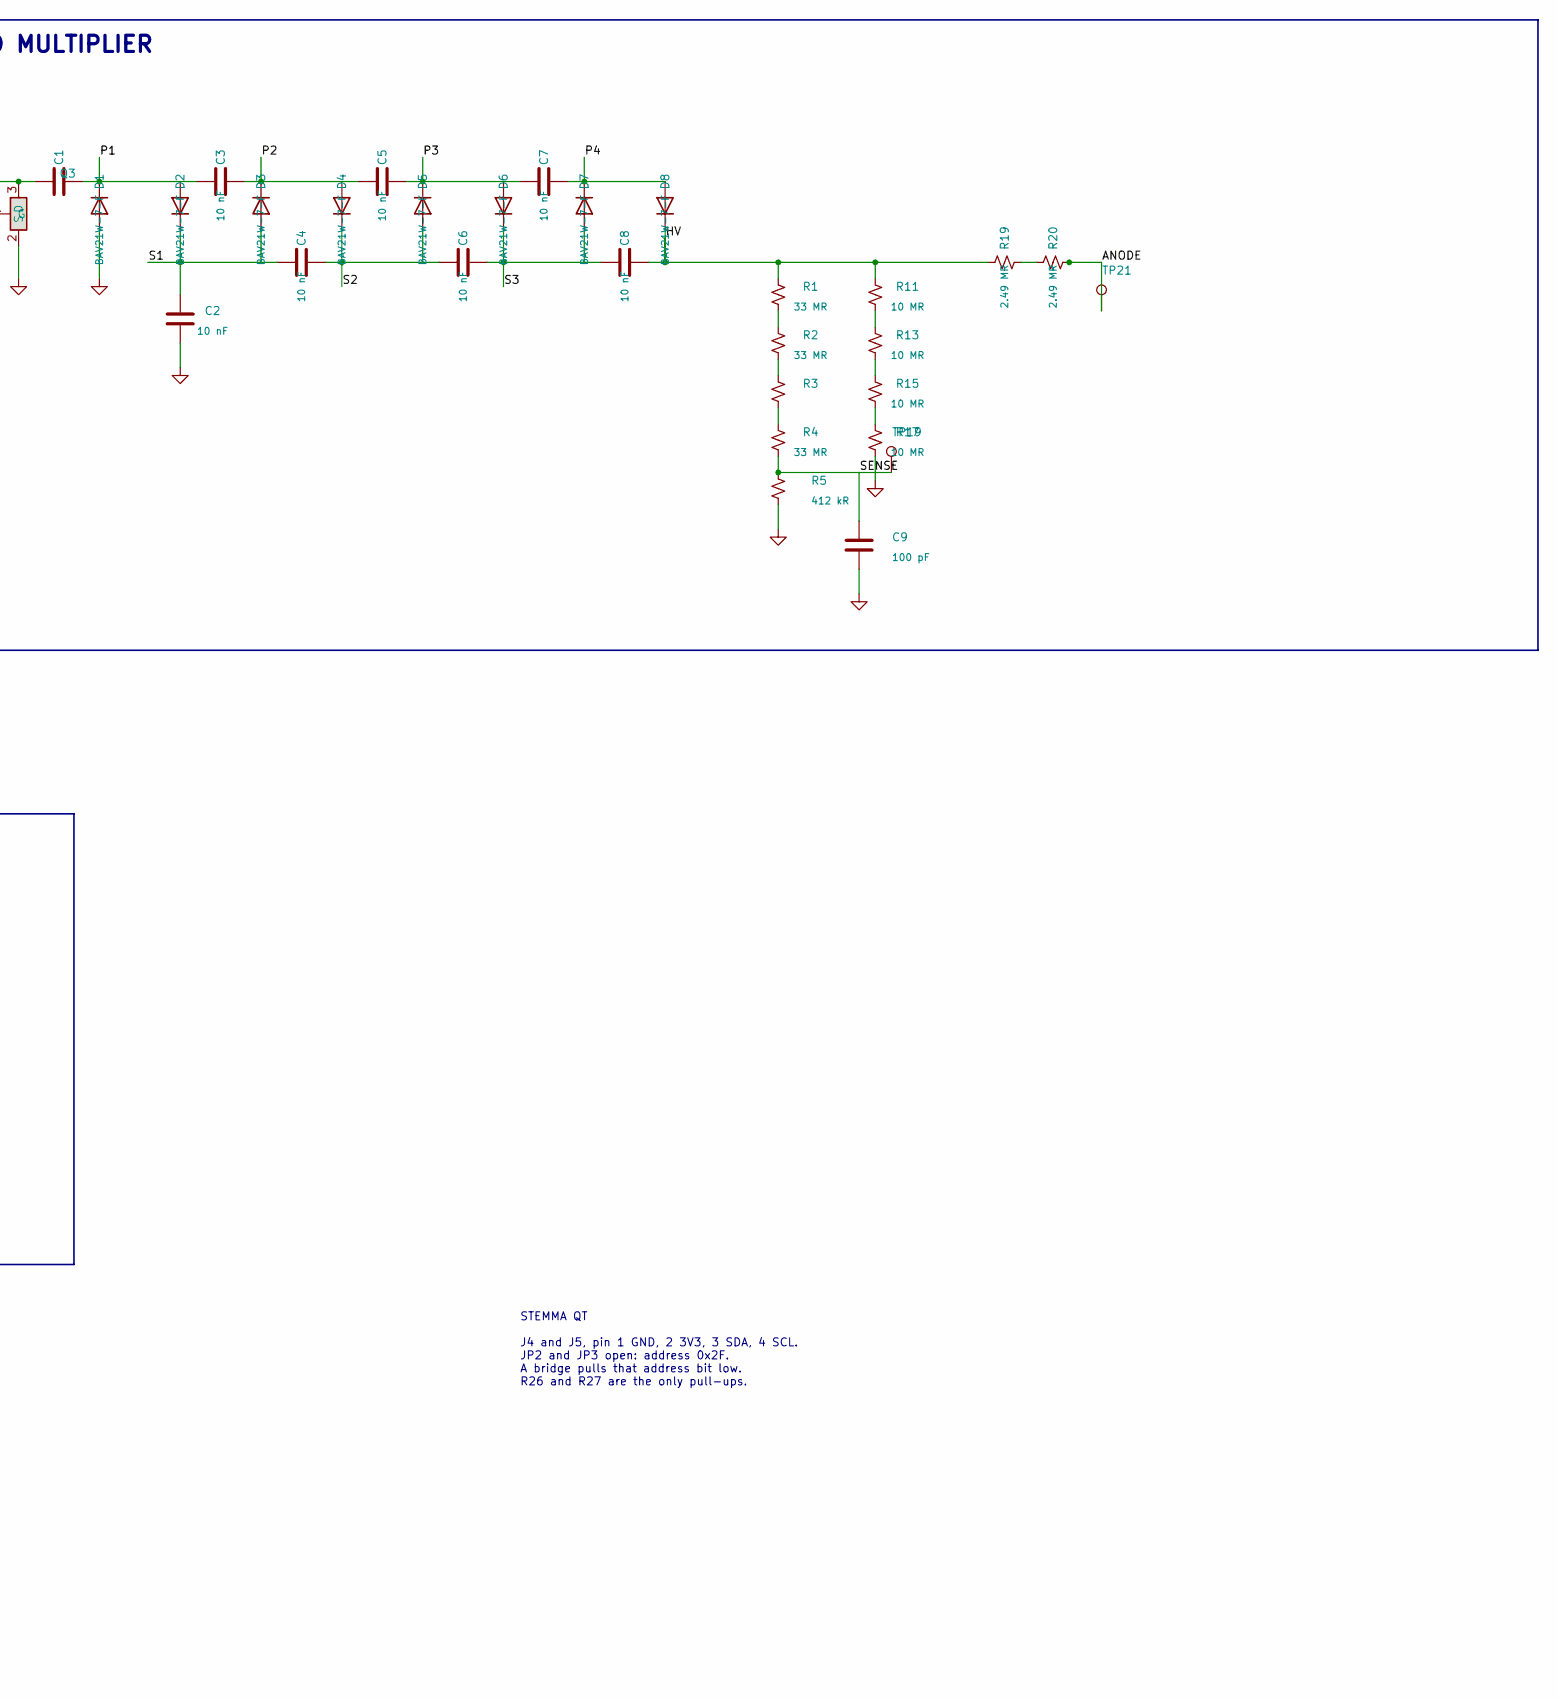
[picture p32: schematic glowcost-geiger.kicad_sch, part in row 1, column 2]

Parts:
C1: 10 nF; C1; MPN C3216C0G2J103JT000N; LCSC C342714
C2: 10 nF; C2; MPN C3216C0G2J103JT000N; LCSC C342714
C3: 10 nF; C3; MPN C3216C0G2J103JT000N; LCSC C342714
C4: 10 nF; C4; MPN C3216C0G2J103JT000N; LCSC C342714
C5: 10 nF; C5; MPN C3216C0G2J103JT000N; LCSC C342714
C6: 10 nF; C6; MPN C3216C0G2J103JT000N; LCSC C342714
C7: 10 nF; C7; MPN C3216C0G2J103JT000N; LCSC C342714
C8: 10 nF; C8; MPN C3216C0G2J103JT000N; LCSC C342714
C9: 100 pF; C9; MPN CL10C101JB8NNNC; LCSC C14858
C11: 100 nF; C_0603_1608Metric; MPN CL10B104KB8NNNC; LCSC C1591
D1: BAV21W-7-F; D1; MPN BAV21W-7-F; LCSC C155214
D2: BAV21W-7-F; D2; MPN BAV21W-7-F; LCSC C155214
D3: BAV21W-7-F; D3; MPN BAV21W-7-F; LCSC C155214
D4: BAV21W-7-F; D4; MPN BAV21W-7-F; LCSC C155214
D5: BAV21W-7-F; D5; MPN BAV21W-7-F; LCSC C155214
D6: BAV21W-7-F; D6; MPN BAV21W-7-F; LCSC C155214
D7: BAV21W-7-F; D7; MPN BAV21W-7-F; LCSC C155214
D8: BAV21W-7-F; D8; MPN BAV21W-7-F; LCSC C155214
D9: KT-0805YG; D_LED; MPN KT-0805YG; LCSC C2292
D10: 1N4148W; D_NEG; MPN 1N4148W; LCSC C81598
GM1: SBM-20
J2, J3: C19184098; MY-AA-03; MPN MY-AA-03; LCSC C19184098
J4, J5: SM04B-SRSS-TB / C160404; JST_SH_SM04B-SRSS-TB_1x04-1MP_P1.00mm_Horizontal; MPN SM04B-SRSS-TB(LF)(SN); LCSC C160404
JP1: CUT = LED OFF; SJ_LED
JP2: A0 open=high; SJ_LED
JP3: A1 open=high; SJ_LED
L1: 1 mH YNR6045-102M; L_6.3x6.3_H3; MPN YNR6045-102M; LCSC C497845
Q1: MMBT3904LT1G; Q1; MPN MMBT3904LT1G; LCSC C81464
Q2: MMBT3904LT1G; Q_LED; MPN MMBT3904LT1G; LCSC C81464
Q3: TN2404K / C468011; SOT-23; MPN TN2404K-T1-GE3; LCSC C468011
R1: 33 MR; R1; MPN FRG2512F3305TS; LCSC C5126202
R2: 33 MR; R2; MPN FRG2512F3305TS; LCSC C5126202
R3: 33 MR; R3; MPN FRG2512F3305TS; LCSC C5126202
R4: 33 MR; R4; MPN FRG2512F3305TS; LCSC C5126202
R5: 412 kR; R5; MPN PTFR0603B412KP9; LCSC C47115896
R6: 1 kR; R_LED; MPN 0603WAF1001T5E; LCSC C21190
R7: 47 kR; R_LB; MPN 0603WAF4702T5E; LCSC C25819
R8: 100 kR; R_LPD; MPN 0603WAF1003T5E; LCSC C25803
R11: 10 MR; R_BL1; MPN 1206W4F1005T5E; LCSC C26119
R13: 10 MR; R_BL2; MPN 1206W4F1005T5E; LCSC C26119
R15: 10 MR; R_BL3; MPN 1206W4F1005T5E; LCSC C26119
R17: 10 MR; R_BL4; MPN 1206W4F1005T5E; LCSC C26119
R19: 2.49 MR; R_A1; MPN CRHV1206AF2M49FKEF
R20: 2.49 MR; R_A2; MPN CRHV1206AF2M49FKEF
R21: 100 kR; R_K; MPN 0603WAF1003T5E; LCSC C25803
R22: 100 kR; R_PROTECT; MPN 0603WAF1003T5E; LCSC C25803
R23: 47 kR; R_COL; MPN 0603WAF4702T5E; LCSC C25819
R24: 1 kR; R_OUT; MPN 0603WAF1001T5E; LCSC C21190
R25: 220 R; R_OUT; MPN 0603WAF2200T5E; LCSC C17577
R26, R27: 4.7 kR; R_OUT; MPN 0603WAF4701T5E; LCSC C23162
TP1: V3V3; TP1
TP2: GND; TP2
TP4: TTL; TP4
TP6: BASE; TP6
TP8: CATHODE; TP8
TP10: SW; TP10
TP19: SENSE; TP19
TP21: ANODE; TP21
TP24: UPDI; TP1
TP28: UART_TX; TP1
U1: ATTINY1616-MNR / C507118; VQFN-20-1EP_3x3mm_P0.4mm_EP1.7x1.7mm; MPN ATTINY1616-MNR; LCSC C507118

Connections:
/A0: JP2.1 (A), U1.15 (PC0)
/A1: JP3.1 (A), U1.16 (PC1)
/ANODE: GM1.1, J2.1, R20.2, TP21.1
/BASE: D10.1 (K), Q1.1 (B), R22.2, TP6.1
/CATHODE: GM1.2, J3.1, R21.1, R22.1, TP8.1
/COLLECTOR: Q1.3 (C), R7.1, R23.2, R24.1, U1.1 (PA2)
/HV: C8.2, D8.1 (K), R1.1, R11.1, R19.1
/HV_PWM: R25.1, U1.12 (PB2)
/P1: C1.2, C3.1, D1.1 (K), D2.2 (A)
/P2: C3.2, C5.1, D3.1 (K), D4.2 (A)
/P3: C5.2, C7.1, D5.1 (K), D6.2 (A)
/P4: C7.2, D7.1 (K), D8.2 (A)
/S1: C2.2, C4.1, D2.1 (K), D3.2 (A)
/S2: C4.2, C6.1, D4.1 (K), D5.2 (A)
/S3: C6.2, C8.1, D6.1 (K), D7.2 (A)
/SCL: J4.4, J5.4, R27.2, U1.14 (PB0)
/SDA: J4.3, J5.3, R26.2, U1.13 (PB1)
/SENSE: C9.1, R4.2, R5.1, TP19.1, U1.7 (PA6)
/SW: C1.1, L1.2, Q3.3 (D), TP10.1
/TTL: R24.2, TP4.1
/UART_TX: TP28.1, U1.20 (PA1)
/UPDI: TP24.1, U1.19 (~RESET/PA0)
unnamed: D9.2 (A), R6.1
unnamed: D9.1 (K), Q2.3 (C)
unnamed: JP1.2 (B), R6.2
unnamed: Q2.1 (B), R7.2, R8.1
unnamed: Q3.1 (G), R25.2
unnamed: R1.2, R2.1
unnamed: R2.2, R3.1
unnamed: R3.2, R4.1
unnamed: R11.2, R13.1
unnamed: R13.2, R15.1
unnamed: R15.2, R17.1
unnamed: R19.2, R20.1

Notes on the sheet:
ARCHITECTURE ATtiny1616. PB2 PWM drives the boost. Counts stay on the MCU. Enable is firmware, not a pin. TTL is a test point. Power enters on STEMMA QT J4 and J5. No Pi header. No hardware OVP divider.
PIN MAP PA0 UPDI. PA1 UART TX, USART0 alternate. PA2 collector. PA6 sense. PB2 HV_PWM. PB1 SDA. PB0 SCL. PC0 A0. PC1 A1. PA3 PA4 PA5 PA7 PB3 PB4 PB5 PC2 PC3 are no-connect. Default TX is PB2, so TX is remapped. TWI alternate is PA1/PA2 and is not used.
BOOST Q3 TN2404K-T1-GE3, 240 V, SOT-23. Pins 1 gate, 2 source, 3 drain. Gate is 3.3 V. L1 YNR6045-102M, 1 mH, 4.5 ohm. C1-C8 10 nF C0G 630 V. D1-D8 BAV21W. Footprint pad 1 is the cathode. Regulated window about 390-420 V. Switch node about 106 V there. 20% is a fault.
SENSE AND TUBE R1-R4 33 MOhm 1% plus R5 412 kOhm 0.1%. PA6, VDD reference. About 1.04 V per count at the tube when VDD is 3.3 V. R11 R13 R15 R17 10 MOhm bleed HV to ground. R19 and R20 2.49 MOhm in series to the anode. D10 cathode clamps Q1 base. SBM-20, about 108 mm. Both ends are C19184098 spring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
STEMMA QT J4 and J5, pin 1 GND, 2 3V3, 3 SDA, 4 SCL. JP2 and JP3 open: address 0x2F. A bridge pulls that address bit low. R26 and R27 are the only pull-ups.
POWER / I2C
MCU
BOOST AND MULTIPLIER
TUBE AND PULSE

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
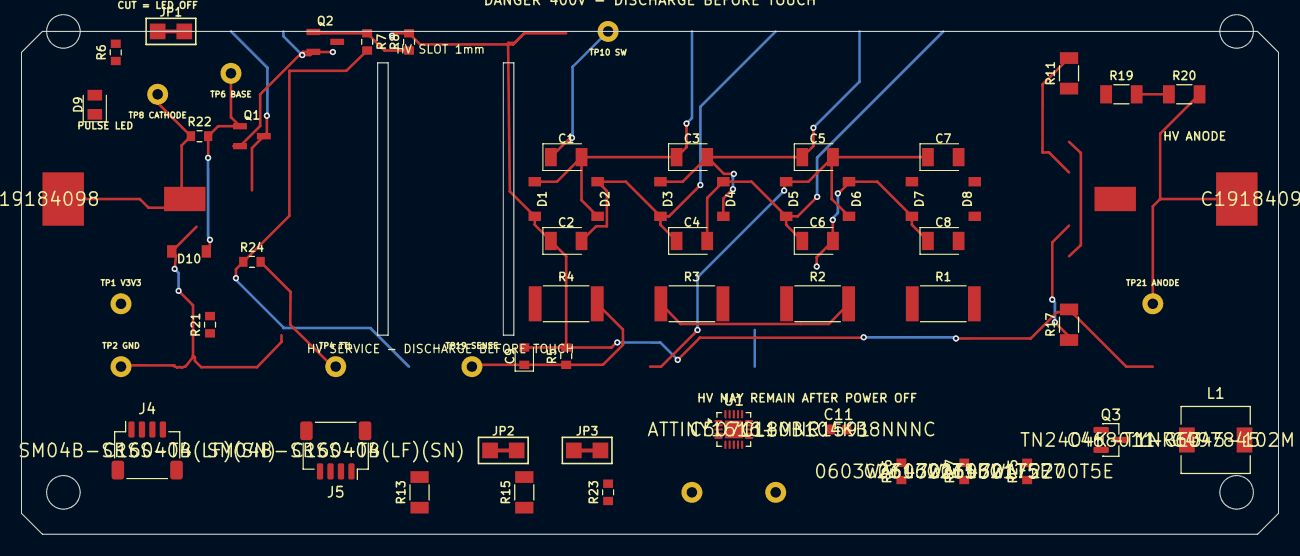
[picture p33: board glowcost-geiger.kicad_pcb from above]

Board: 2 copper layers, 120.0 x 48.0 mm, 68 parts (0 on the bottom side), 36 nets.

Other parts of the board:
H1: MountingHole_3.2mm; H1
H2: MountingHole_3.2mm; H2
H3: MountingHole_3.2mm; H3
H4: MountingHole_3.2mm; H4
MECH1: Tube_Assembly_Model

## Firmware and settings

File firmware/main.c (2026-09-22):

#define F_CPU 20000000UL

#include <avr/io.h>
#include <avr/interrupt.h>
#include <avr/cpufunc.h>
#include <avr/wdt.h>
#include <stdint.h>
#include <stdbool.h>
#include "pins.h"
#include "regs.h"

/*
 * ATtiny1616 HV regulator and I2C slave.
 *
 * CTC-5 / STS-5 and SBM-20 share this ~400 V bias. The tube register
 * only labels which one is fitted. PA6 is the feedback (VDD reference,
 * about 1.04 V of tube voltage per count at 3.3 V). TCA0 WO2 on PB2
 * is 10 kHz. The loop steps one count every 10 ms toward the setpoint
 * and will not go past 20% duty. A stuck 20% with the sense still low
 * latches off. TWI0 is PB1 SDA / PB0 SCL.
 */

#define HV_OVP_ADC      405u /* ~420 V at 3.3 V */
#define HV_RECOVER_ADC  376u /* ~390 V */
#define HV_TARGET_ADC   386u /* ~400 V */
#define HV_TARGET_MIN   200u /* ~208 V, lowest host setpoint */
#define HV_BAND         8u
#define HV_PWM_PERIOD   2000u /* 20 MHz / 2000 = 10 kHz */
#define HV_DUTY_MAX     400u  /* 20% ceiling */
#define HV_DUTY_START   20u   /* 1% */
#define HV_CEIL_TICKS   20u   /* 200 ms at the ceiling with sense still low */
#define HV_TICKS_10MS   100u  /* TCA overflows of 100 us */
#define PULSE_BLANK     3u    /* 200–300 us, rejects a bouncing edge */

static volatile uint32_t pulse_count;
static volatile uint16_t pulse_window;
static volatile uint16_t cps_latched;
static volatile uint16_t hv_sense;
static volatile uint16_t hv_duty;
static volatile uint16_t hv_target = HV_TARGET_ADC;
static volatile uint8_t pulse_blank;
static volatile uint8_t tube_id = TUBE_EITHER;
static volatile bool hv_en;
static volatile bool hv_ovp;
static volatile bool hv_fail;
static volatile bool hv_due;
static volatile bool report_due;

static uint8_t i2c_ptr;
static bool i2c_ptr_set;
static uint8_t snap[REG_MAP_LEN];

static uint16_t load16(const volatile uint16_t *p) {
    uint16_t v;
    uint8_t s = SREG;
    cli();
    v = *p;
    SREG = s;
    return v;
}

static void store16(volatile uint16_t *p, uint16_t v) {
    uint8_t s = SREG;
    cli();
    *p = v;
    SREG = s;
}

static uint32_t load32(const volatile uint32_t *p) {
    uint32_t v;
    uint8_t s = SREG;
    cli();
    v = *p;
    SREG = s;
    return v;
}

static void clock_init(void) {
    /* Factory prescaler is 6, which would leave 3.33 MHz. */
    ccp_write_io((void *)&CLKCTRL.MCLKCTRLB, 0);
}

static void uart_init(void) {
    PORTMUX.CTRLB = PORTMUX_USART0_ALTERNATE_gc; /* TX -> PA1 */
    PORTA.DIRSET = UART_TX_bm;
    /* BAUD = 64 * F_CPU / (16 * 115200) = 694. */
    USART0.BAUD = 694;
    USART0.CTRLB = USART_TXEN_bm;
}

static void uart_putc(char c) {
    while (!(USART0.STATUS & USART_DREIF_bm)) {}
    USART0.TXDATAL = (uint8_t)c;
}

static void uart_puts(const char *s) {
    while (*s) uart_putc(*s++);
}

static void uart_u32(uint32_t v) {
    char b[11];
    uint8_t i = 0;
    if (!v) { uart_putc('0'); return; }
    while (v && i < sizeof b) {
        b[i++] = (char)('0' + (v % 10u));
        v /= 10u;
    }
    while (i) uart_putc(b[--i]);
}

static void uart_hex8(uint8_t v) {
    static const char h[] = "0123456789ABCDEF";
    uart_putc(h[v >> 4]);
    uart_putc(h[v & 0x0Fu]);
}

static void adc_init(void) {
    /* The 412 kOhm sense leg needs a long sample. */
    ADC0.CTRLC = ADC_PRESC_DIV64_gc | ADC_REFSEL_VDDREF_gc;
    ADC0.SAMPCTRL = 31;
    ADC0.CTRLA = ADC_ENABLE_bm;
}

static uint16_t adc_read(uint8_t mux) {
    ADC0.MUXPOS = mux;
    ADC0.COMMAND = ADC_STCONV_bm;
    while (!(ADC0.INTFLAGS & ADC_RESRDY_bm)) {}
    ADC0.INTFLAGS = ADC_RESRDY_bm;
    return ADC0.RES;
}

static void hv_set_duty(uint16_t duty) {
    uint8_t s;
    if (duty > HV_DUTY_MAX) duty = HV_DUTY_MAX;
    s = SREG;
    cli();
    hv_duty = duty;
    TCA0.SINGLE.CMP2 = duty;
    SREG = s;
}

static void hv_pwm_init(void) {
    PORTB.DIRSET = HV_PWM_bm;
    PORTB.OUTCLR = HV_PWM_bm;
    TCA0.SINGLE.PER = HV_PWM_PERIOD - 1u;
    TCA0.SINGLE.CMP2 = 0;
    TCA0.SINGLE.CTRLB =
        TCA_SINGLE_WGMODE_SINGLESLOPE_gc | TCA_SINGLE_CMP2EN_bm;
    TCA0.SINGLE.INTCTRL = TCA_SINGLE_OVF_bm;
    TCA0.SINGLE.CTRLA =
        TCA_SINGLE_CLKSEL_DIV1_gc | TCA_SINGLE_ENABLE_bm;
}

static void hv_stop(void) {
    hv_ovp = false;
    hv_fail = false;
    hv_set_duty(0);
}

static void hv_request(bool on) {
    hv_en = on;
    if (!on) hv_stop();
    else if (load16(&hv_duty) == 0) hv_set_duty(HV_DUTY_START);
}

static void hv_service(void) {
    uint16_t sense = adc_read(HV_SENSE_ADC);
    uint16_t target = load16(&hv_target);
    uint16_t duty = load16(&hv_duty);
    static uint8_t ceil_ticks;

    store16(&hv_sense, sense);
    if (!hv_en || hv_fail) {
        hv_set_duty(0);
        ceil_ticks = 0;
        return;
    }
    if (sense >= HV_OVP_ADC) {
        hv_ovp = true;
        hv_set_duty(0);
        ceil_ticks = 0;
        return;
    }
    if (hv_ovp) {
        if (sense <= HV_RECOVER_ADC) {
            hv_ovp = false;
            hv_set_duty(HV_DUTY_START);
        }
        return;
    }
    if (sense + HV_BAND < target) {
        if (duty < HV_DUTY_MAX) {
            hv_set_duty((uint16_t)(duty + 1u));
            ceil_ticks = 0;
        } else if (++ceil_ticks >= HV_CEIL_TICKS) {
            hv_fail = true;
            hv_set_duty(0);
        }
    } else {
        ceil_ticks = 0;
        if (sense > target + HV_BAND && duty > 0)
            hv_set_duty((uint16_t)(duty - 1u));
    }
}

static void pulse_init(void) {
    PORTA.DIRCLR = PULSE_IN_bm;
    PORTA.PIN2CTRL = PORT_PULLUPEN_bm | PORT_ISC_RISING_gc;
}

static void gpio_init(void) {
    PORTC.DIRCLR = ADDR_A0_bm | ADDR_A1_bm;
    PORTC.PIN0CTRL = PORT_PULLUPEN_bm;
    PORTC.PIN1CTRL = PORT_PULLUPEN_bm;
}

static uint8_t address_bits(void) {
    uint8_t a = 0;
    if (!(PORTC.IN & ADDR_A0_bm)) a |= 1u;
    if (!(PORTC.IN & ADDR_A1_bm)) a |= 2u;
    return a;
}

static uint8_t i2c_address(void) {
    return (uint8_t)(0x2Fu + address_bits());
}

static void counts_clear(void) {
    uint8_t s = SREG;
    cli();
    pulse_count = 0;
    pulse_window = 0;
    SREG = s;
}

static uint8_t status_byte(void) {
    uint8_t st = 0;
    uint16_t sense = load16(&hv_sense);
    uint16_t target = load16(&hv_target);
    if (hv_en) st |= ST_HV_EN;
    if (hv_ovp) st |= ST_OVP;
    if (hv_fail) st |= ST_FAIL;
    if (hv_en && !hv_ovp && !hv_fail && load16(&hv_duty) > 0 &&
        sense + HV_BAND >= target && sense <= target + HV_BAND)
        st |= ST_REG;
    return st;
}

static void snapshot(void) {
    uint32_t count = pulse_count;
    uint16_t cps = load16(&cps_latched);
    uint16_t sense = load16(&hv_sense);
    uint16_t duty = load16(&hv_duty);
    uint16_t target = load16(&hv_target);
    uint8_t i;

    for (i = 0; i < REG_MAP_LEN; i++) snap[i] = 0xFF;
    snap[REG_ID] = REG_ID_VALUE;
    snap[REG_FW] = REG_FW_VALUE;
    snap[REG_STATUS] = status_byte();
    snap[REG_CTRL] = hv_en ? CTRL_HV_EN : 0;
    snap[REG_COUNT + 0] = (uint8_t)count;
    snap[REG_COUNT + 1] = (uint8_t)(count >> 8);
    snap[REG_COUNT + 2] = (uint8_t)(count >> 16);
    snap[REG_COUNT + 3] = (uint8_t)(count >> 24);
    snap[REG_CPS] = (uint8_t)cps;
    snap[REG_CPS + 1] = (uint8_t)(cps >> 8);
    snap[REG_HV_ADC] = (uint8_t)sense;
    snap[REG_HV_ADC + 1] = (uint8_t)(sense >> 8);
    snap[REG_DUTY] = (uint8_t)duty;
    snap[REG_DUTY + 1] = (uint8_t)(duty >> 8);
    snap[REG_TARGET] = (uint8_t)target;
    snap[REG_TARGET + 1] = (uint8_t)(target >> 8);
    snap[REG_TUBE] = tube_id;
    snap[REG_CMD] = 0;
}

static void reg_write(uint8_t reg, uint8_t val) {
    uint16_t target;
    switch (reg) {
    case REG_CTRL:
        hv_request((val & CTRL_HV_EN) != 0);
        break;
    case REG_TARGET:
        target = (uint16_t)((load16(&hv_target) & 0xFF00u) | val);
        if (target < HV_TARGET_MIN) target = HV_TARGET_MIN;
        if (target >= HV_OVP_ADC) target = HV_OVP_ADC - 1u;
        store16(&hv_target, target);
        break;
    case REG_TARGET + 1:
        target = (uint16_t)((load16(&hv_target) & 0x00FFu) | ((uint16_t)val << 8));
        if (target < HV_TARGET_MIN) target = HV_TARGET_MIN;
        if (target >= HV_OVP_ADC) target = HV_OVP_ADC - 1u;
        store16(&hv_target, target);
        break;
    case REG_TUBE:
        if (val <= TUBE_SBM20) tube_id = val;
        break;
    case REG_CMD:
        if (val == REG_CMD_CLEAR) counts_clear();
        break;
    default:
        break;
    }
}

static void twi_init(uint8_t addr7) {
    /* Default TWI pins are PB1 SDA and PB0 SCL. ADDR[7:1], no general call. */
    TWI0.SADDR = (uint8_t)(addr7 << 1);
    TWI0.SCTRLA = TWI_DIEN_bm | TWI_APIEN_bm | TWI_PIEN_bm | TWI_ENABLE_bm;
}

ISR(TWI0_TWIS_vect) {
    uint8_t s = TWI0.SSTATUS;

    if (s & (TWI_BUSERR_bm | TWI_COLL_bm)) {
        TWI0.SSTATUS = (uint8_t)(s & (TWI_BUSERR_bm | TWI_COLL_bm));
        i2c_ptr_set = false;
        TWI0.SCTRLB = TWI_SCMD_COMPTRANS_gc;
        return;
    }
    if (s & TWI_APIF_bm) {
        if (s & TWI_AP_bm) {
            if (s & TWI_DIR_bm) {
                snapshot();
                TWI0.SDATA = (i2c_ptr < REG_MAP_LEN) ? snap[i2c_ptr] : 0xFF;
                if (i2c_ptr < 255) i2c_ptr++;
            } else {
                i2c_ptr_set = false;
            }
            TWI0.SCTRLB = TWI_ACKACT_ACK_gc | TWI_SCMD_RESPONSE_gc;
        } else {
            i2c_ptr_set = false;
            TWI0.SCTRLB = TWI_SCMD_COMPTRANS_gc;
        }
        return;
    }
    if (s & TWI_DIF_bm) {
        if (s & TWI_DIR_bm) {
            if (s & TWI_RXACK_bm) {
                TWI0.SCTRLB = TWI_SCMD_COMPTRANS_gc;
            } else {
                TWI0.SDATA = (i2c_ptr < REG_MAP_LEN) ? snap[i2c_ptr] : 0xFF;
                if (i2c_ptr < 255) i2c_ptr++;
                TWI0.SCTRLB = TWI_ACKACT_ACK_gc | TWI_SCMD_RESPONSE_gc;
            }
        } else {
            uint8_t b = TWI0.SDATA;
            if (!i2c_ptr_set) {
                i2c_ptr = b;
                i2c_ptr_set = true;
            } else {
                reg_write(i2c_ptr, b);
                if (i2c_ptr < 255) i2c_ptr++;
            }
            TWI0.SCTRLB = TWI_ACKACT_ACK_gc | TWI_SCMD_RESPONSE_gc;
        }
        return;
    }
    TWI0.SCTRLB = TWI_SCMD_COMPTRANS_gc;
}

ISR(TCA0_OVF_vect) {
    static uint8_t ticks;
    TCA0.SINGLE.INTFLAGS = TCA_SINGLE_OVF_bm;
    if (pulse_blank) pulse_blank--;
    if (++ticks >= HV_TICKS_10MS) {
        ticks = 0;
        hv_due = true;
    }
}

ISR(RTC_PIT_vect) {
    RTC.PITINTFLAGS = RTC_PI_bm;
    store16(&cps_latched, pulse_window);
    pulse_window = 0;
    report_due = true;
}

ISR(PORTA_PORT_vect) {
    uint8_t flags = PORTA.INTFLAGS;
    PORTA.INTFLAGS = flags;
    if ((flags & PULSE_IN_bm) && pulse_blank == 0) {
        pulse_count++;
        pulse_window++;
        pulse_blank = PULSE_BLANK;
    }
}

static void rtc_init(void) {
    RTC.CLKSEL = RTC_CLKSEL_INT32K_gc;
    while (RTC.PITSTATUS & RTC_CTRLBUSY_bm) {}
    RTC.PITCTRLA = RTC_PERIOD_CYC32768_gc | RTC_PITEN_bm;
    RTC.PITINTCTRL = RTC_PI_bm;
}

int main(void) {
    uint8_t addr;

    clock_init();
    wdt_enable(WDTO_1S);
    gpio_init();
    uart_init();
    adc_init();
    pulse_init();
    hv_pwm_init();
    rtc_init();
    addr = i2c_address();
    twi_init(addr);
    sei();

    uart_puts("gLowCost-geiger ATtiny1616\r\naddr=0x");
    uart_hex8(addr);
    uart_puts(" STS-5/SBM-20 HV off\r\n");

    for (;;) {
        wdt_reset();
        if (hv_due) {
            hv_due = false;
            hv_service();
        }
        if (report_due) {
            report_due = false;
            uart_puts("count=");
            uart_u32(load32(&pulse_count));
            uart_puts(" cps=");
            uart_u32(load16(&cps_latched));
            uart_puts(" hv=");
            uart_u32(load16(&hv_sense));
            uart_puts(" duty=");
            uart_u32(load16(&hv_duty));
            if (hv_fail) uart_puts(" FAIL");
            else if (hv_ovp) uart_puts(" OVP");
            else if (!hv_en) uart_puts(" OFF");
            uart_puts("\r\n");
        }
    }
}

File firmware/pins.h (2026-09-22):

#ifndef GLOWCOST_PINS_H
#define GLOWCOST_PINS_H

#include <avr/io.h>

/*
 * ATtiny1616-MNR pin map (schematic U1, VQFN-20).
 * TWI0 defaults are PB1 SDA and PB0 SCL. PA4/PA5 are not TWI.
 * USART0 TX uses the alternate mux on PA1 — default TX is PB2 (HV_PWM).
 * PA3, PA4, PA5, PA7, PB3, PB4, PB5, PC2, PC3 are no-connect.
 * Boost enable is firmware. There is no enable pin and no 3V3 sense.
 */
#define PULSE_IN_bm       PIN2_bm   /* PA2 COLLECTOR */
#define HV_SENSE_ADC      6u        /* PA6 SENSE */
#define SDA_bm            PIN1_bm   /* PB1 TWI0 SDA */
#define SCL_bm            PIN0_bm   /* PB0 TWI0 SCL */
#define ADDR_A0_bm        PIN0_bm   /* PC0 */
#define ADDR_A1_bm        PIN1_bm   /* PC1 */
#define HV_PWM_bm         PIN2_bm   /* PB2 boost gate via R25 */
#define UART_TX_bm        PIN1_bm   /* PA1 alternate USART0 TX */
#define UPDI_bm           PIN0_bm   /* PA0 */

#endif

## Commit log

2026-09-15 Initialize 3.3V Raspberry Pi Geiger module design and SPICE studies
    [results.csv]
2026-09-15 Clean annotated schematic and document performance and assembly planning
2026-09-15 Estimate 25 and 50 board production costs with supplier price tiers
2026-09-15 Budget five prototype boards with owned tubes and list unresolved parts
2026-09-15 Add DNP tube clips and select rated schematic and controller parts
    [review-bom.csv]
2026-09-15 Add basic PCB placement, 3D preview and documented layer renders
    [placement.csv]
2026-09-15 Compact under-tube placement and add recovered tube and generated clip CAD
    [.75in PVC.ipt, 8907K48 045 Phosphate Rod.ipt, Acrylic Housing.iam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]
2026-09-15 Route compact board study and render tube and clip assembly
    [assembly.blend, placement.csv]
2026-09-15 Add through-hole probes, HV warnings and cuttable 0805 pulse LED
    [assembly.blend, placement.csv, review-bom.csv]
2026-09-16 Add native KiCad prototype with local models and verified netlist
    [C142864.step, C_0603_1608Metric.step, C_1206_3216Metric.step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]
2026-09-16 Normalize generated review text and preserve vendor STEP files
    [reference-map.csv]
2026-09-16 Replace behavioral parts and remove tscircuit workflow
    [MSOP-8-1EP_3x3mm_P0.65mm_EP1.68x1.88mm.step, SOIC-8_3.9x4.9mm_P1.27mm.step, glowcost-geiger.kicad_sch]
2026-09-16 Clean KiCad sheet and place implementation parts
    [glowcost-geiger.kicad_pcb]
2026-09-16 Move Pi connector to tube end and use thin board
2026-09-16 Apply end connector placement and 0.8mm stackup
    [glowcost-geiger.kicad_pcb]
2026-09-16 Center Pi connector on left tube end
    [glowcost-geiger.kicad_pcb]
2026-09-16 Rebuild sheet metal clip and narrow PCB outline
    [C142864.FCStd, C142864.step, C142864.stl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]
2026-09-16 Refresh documentation renders and organize review gallery
    [assembly.blend]
2026-09-16 Document STEMMA QT solder address selection
2026-09-16 Simplify README and refresh render gallery
    [assembly.blend]
2026-09-16 Add ATtiny1616 firmware bringup and UART diagnostics
2026-09-17 Reserve raw pulse output and select safer I2C default
2026-09-17 Add HV isolation slots and clean assembly notes
    [glowcost-geiger.kicad_pcb]
2026-09-17 Refresh bright assembly views
    [assembly.blend]
2026-09-17 Add Jev semantic PCB review workflow
2026-09-19 Add ATtiny1616-only schematic and STEMMA/boost block
    Replace U1/U2 behavioral boundaries with ATtiny1616-MNR PWM HV drive,
    dual STEMMA QT, and boost FET/inductor. Sync pin map, handoff docs, and
    firmware pin headers.
    [JST_SH_SM04B-SRSS-TB_1x04-1MP_P1.00mm_Horizontal.step, glowcost-geiger.kicad_sch, review-bom.csv]
2026-09-19 Tidy ATtiny schematic ERC and refresh jev report
    Wire probe TP/power-flag nets, re-anchor boost/decap labels, clear all
    ERC errors. Jev deterministic gate refreshed (API key not available).
    [glowcost-geiger.kicad_sch]
2026-09-19 Apply Jev schematic layout winners and add decision helper
    Cluster probes on an edge strip, annotate left-to-right block frames,
    keep label-based long nets. Add jev_schematic_review helper/report;
    refresh PCB jev answers. ERC errors remain 0; core nets unchanged.
    [glowcost-geiger.kicad_sch]
2026-09-19 Polish ATtiny schematic layout and clear overlaps
    Boost/STEMMA placement, probe strip pitch, hide noisy fields; ERC 0 and core nets intact.
    [glowcost-geiger.kicad_sch]
2026-09-19 Reorganize like x.drop-beacon and remove Jev
    Move KiCad to pcb/, keep a single readme.md, lean docs/images and scripts,
    add manufacturing notes, and delete Jev helpers plus stale generated docs.
    [.75in PVC.ipt, 8907K48 045 Phosphate Rod.ipt, Acrylic Housing.iam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]
2026-09-19 Add tube STEP model for KiCad 3D
    Export cad/models/tube.stl via FreeCAD to pcb/models/tube.step and point the
    tube footprint at it. Includes a small FreeCADCmd re-export script.
    [glowcost-geiger.kicad_pcb, tube.step]
2026-09-19 Organize schematic like x.drop-beacon
    Beacon-style A2 frames and section titles, DESIGN NOTES column, and a filled
    title block. Connectivity unchanged; ERC still 0 errors.
    [glowcost-geiger.kicad_sch]
2026-09-19 Fix tube anode/cathode nets, refresh SPICE, document electrical review
    Reattach R20 to ANODE and R21/R22 to CATHODE after layout cleanup left
    them floating. Point simulate.py at docs/sim, annotate the ATtiny-PWM
    deck, and update the README with review notes plus sim diagrams.
    [glowcost-geiger.kicad_sch, results.csv]
2026-09-19 Swap L1 to YNR6045-102M and add firmware SENSE OVP
    Replace B82442T1105K050 (9.5 Ω DCR, wrong 1210 footprint) with
    YNR6045-102M / C497845 (4.5 Ω, 6×6 mm, 300 mA Isat). SPICE DCR=4.5;
    suite re-passed. Firmware drives HV_PWM with soft-start and clamps via
    PA6 SENSE (~420 V trip / ~390 V recover) since no hardware OVP remains.
    [glowcost-geiger.kicad_sch, results.csv]
2026-09-21 Document MCU HV duty range and sense readback.
    PWM at 1 µA spans about 37 V at 1% duty to 604 V at 20%, 1.5 V per timer count, and the 60 V FET limit lands near 233 V. PA6 readback is 1.04 V per count. The L1 sheet note now matches YNR6045-102M.
    [duty-sweep.csv, glowcost-geiger.kicad_sch]
2026-09-22 Redraw the ATtiny sheet and refresh the HV figures.
    Drop the Pi header and the unused dividers, put TWI on PB1/PB0, and rate the boost for the 390–420 V window. Rerun the ngspice suite and replace the old board renders and duplicate plots with the current schematic crops and charts.
2026-09-22 Redraw the ATtiny sheet and publish the rerun HV charts.
    Move TWI to PB1/PB0, drop the Pi header and the unused dividers, and rate Q3 as the 240 V TN2404K. The ngspice suite was rerun; the README is the current schematic crops and the new duty, startup, an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
    [duty-sweep.csv, glowcost-geiger.kicad_sch]
2026-09-22 Point J4 and J5 at the SRSS land and correct C11.
    The STEMMA connectors stay SM04B-SRSS-TB and now use the stock JST SH footprint. C11 stays 100 nF and is CL10B104KB8NNNC (LCSC C1591) on a 0603 land. The board file is unchanged. Notes record that BAV21W-7-F is a 200 V part and the deck's 250 V diode is generic.
    [glowcost-geiger.kicad_sch]
2026-09-22 Add the I2C slave and hold the boost off until enable.
    CTC-5/STS-5 and SBM-20 share the ~400 V loop. Boot leaves PWM at zero until the host sets CTRL bit 0. Counts are a running total plus the previous second.
    [glowcost-geiger.kicad_sch]
2026-09-22 Update the board for the SBM-20 and the firmware faults.
    J2 and J3 are both C19184098. The ATtiny, boost switch, and STEMMA QT connectors sit on a bay added along the lower edge. Multiplier copper that still matched the sheet was kept; the new nets are not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
    [MY-AA-03.step, glowcost-geiger.kicad_pcb, glowcost-geiger.kicad_sch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]

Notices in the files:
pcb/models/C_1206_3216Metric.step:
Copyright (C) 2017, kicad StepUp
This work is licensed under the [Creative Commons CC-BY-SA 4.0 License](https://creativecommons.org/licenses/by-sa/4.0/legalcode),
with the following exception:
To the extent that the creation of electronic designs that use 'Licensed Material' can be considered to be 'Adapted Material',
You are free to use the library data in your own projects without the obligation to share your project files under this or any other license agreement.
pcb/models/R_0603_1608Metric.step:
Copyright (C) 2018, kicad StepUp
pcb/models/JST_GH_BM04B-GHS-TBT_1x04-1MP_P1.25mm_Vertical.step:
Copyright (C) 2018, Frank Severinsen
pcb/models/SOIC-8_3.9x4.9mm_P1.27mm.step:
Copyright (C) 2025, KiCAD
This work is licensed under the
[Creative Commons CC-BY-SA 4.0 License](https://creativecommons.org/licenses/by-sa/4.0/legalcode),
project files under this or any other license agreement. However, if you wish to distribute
